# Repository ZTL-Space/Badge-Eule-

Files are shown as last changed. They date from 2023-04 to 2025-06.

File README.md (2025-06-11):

# Entnervte Eule - Lötanleitung

## Einleitung
Die Entnervte Eule ist ein einfacher Bausatz zum selber Zusammenlöten, der im ZTL, dem Zentrum für Technikkultur in Landau, designed wurde.

Die Eule gibt es in 12 verschiedenen Varianten zur Wahl.
Die Platine ist entweder Weiß/Silbern oder Schwarz/Gold.
Die LEDs, welche die Augen darstellen, gibt es in Rot, Gelb, Grün, Blau, langsamer Farbwechsel und schneller Farbwechsel.

## Auspacken

Die Bauteile kommen in einem wiederverschließbaren Beutel, den ihr am Ende mit nach Hause nehmen oder uns zurück geben könnt. Dann wird er wiederverwendet.

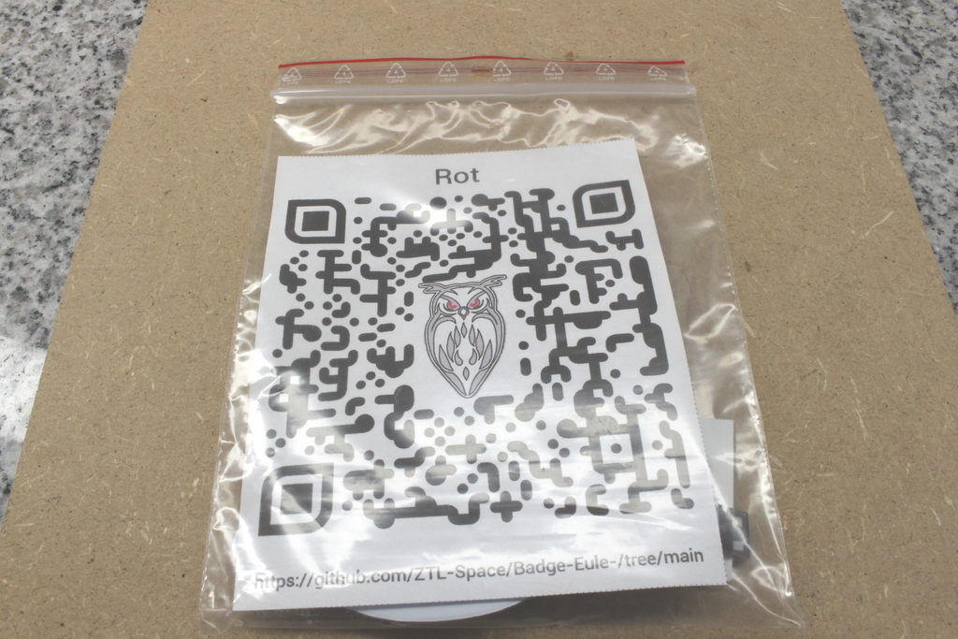
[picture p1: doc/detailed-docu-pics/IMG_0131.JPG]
Wiederverschließbarer Beutel


## Die Bauteile

Folgende Bauteile sollten in der Tüte sein:

- Platine
- Papiergurt mit 2 Widerständen
- Plastikgurt mit 2 LEDs
- Schiebeschalter
- Knopfzellenhalter
- Knopfzelle

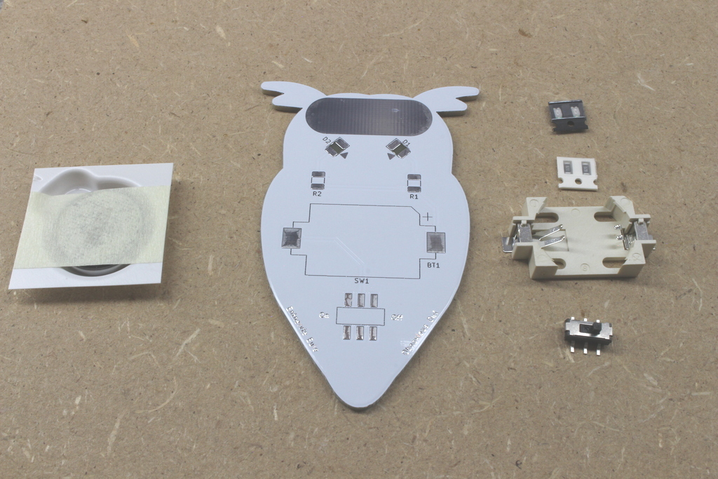
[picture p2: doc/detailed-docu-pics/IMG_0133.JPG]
Bauteile


## Widerstände - R1 und R2

### Auspacken

Zuerst musst du die beiden Widerstände aus dem Papiergurt befreien, indem du mit der Pinzette den Plastikfilm abziehst. Mach das am besten über dem Holzbrett, sodass die Widerstände nicht verloren gehen, sollten sie herunterfallen.

<p float="left">
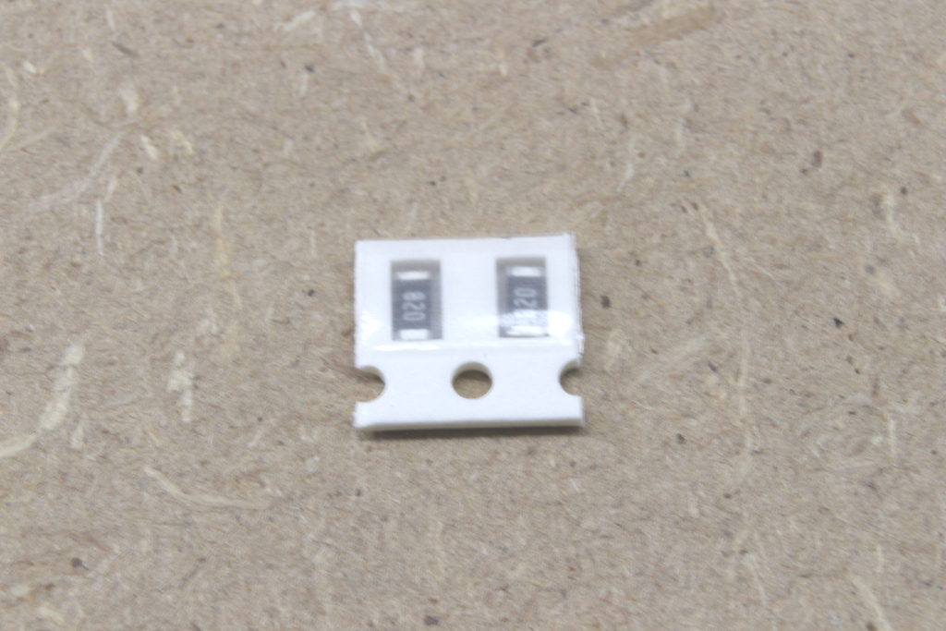
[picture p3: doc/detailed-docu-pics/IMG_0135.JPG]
  
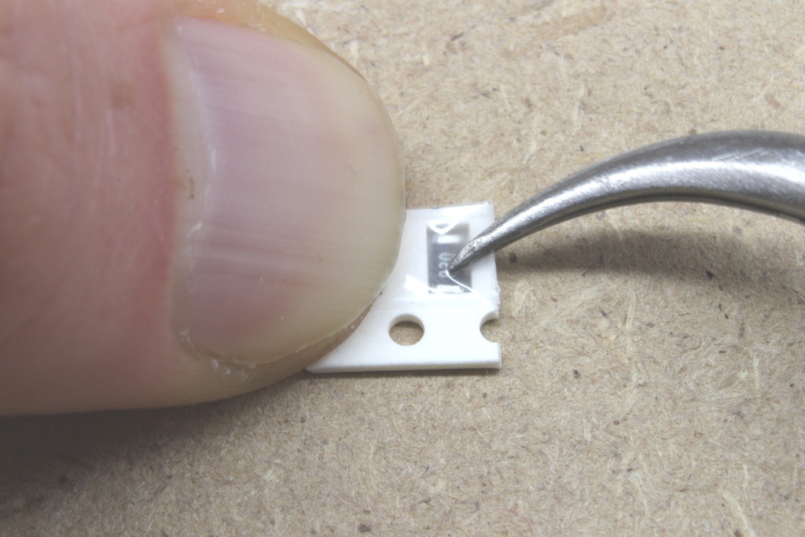
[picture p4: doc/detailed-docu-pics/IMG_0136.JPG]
  
</p>

<p float="left">
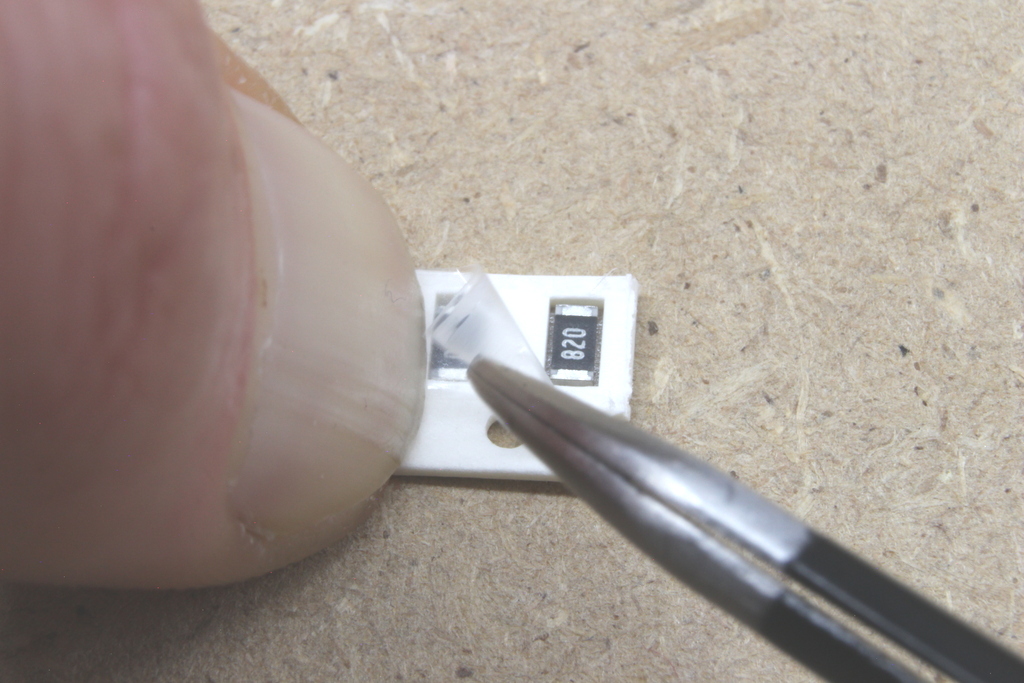
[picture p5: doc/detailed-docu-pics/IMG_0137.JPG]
  
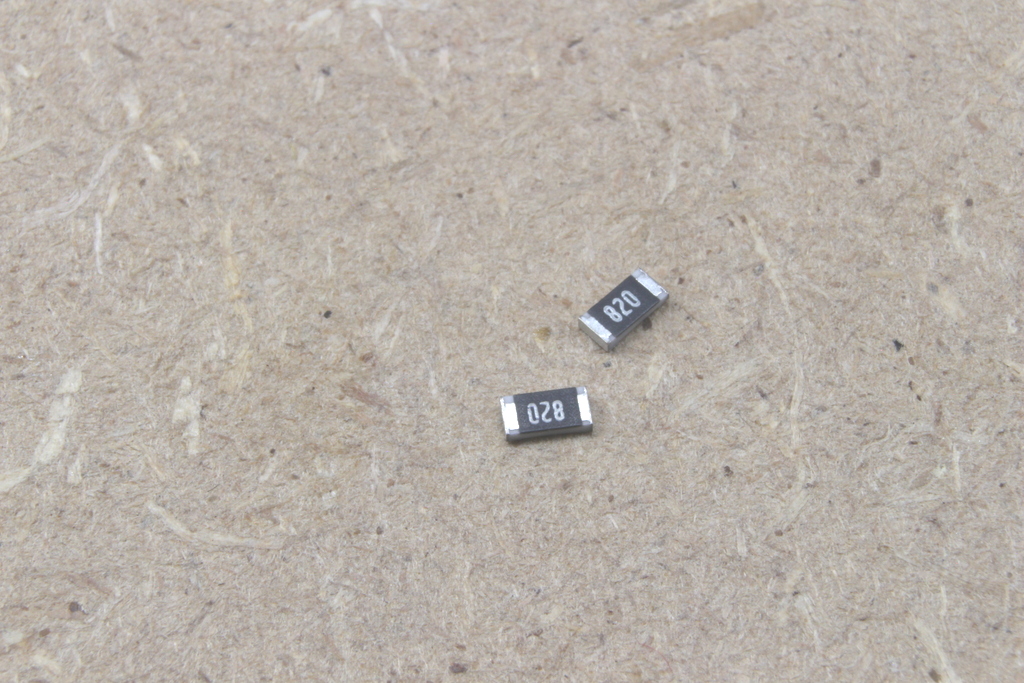
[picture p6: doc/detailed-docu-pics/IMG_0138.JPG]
  
</p>

### Vorverzinnen

Nun musst du eins der beiden Pads von R1 vorverzinnen. Dazu setzt du die Spitze des Lötkolbens auf das Pad und fügst Lötzinn hinzu bis es schmilzt und sich ein kleiner Hügel auf dem Pad bildet. 

Bitte lass das zweite Pad noch frei.

<p float="left">
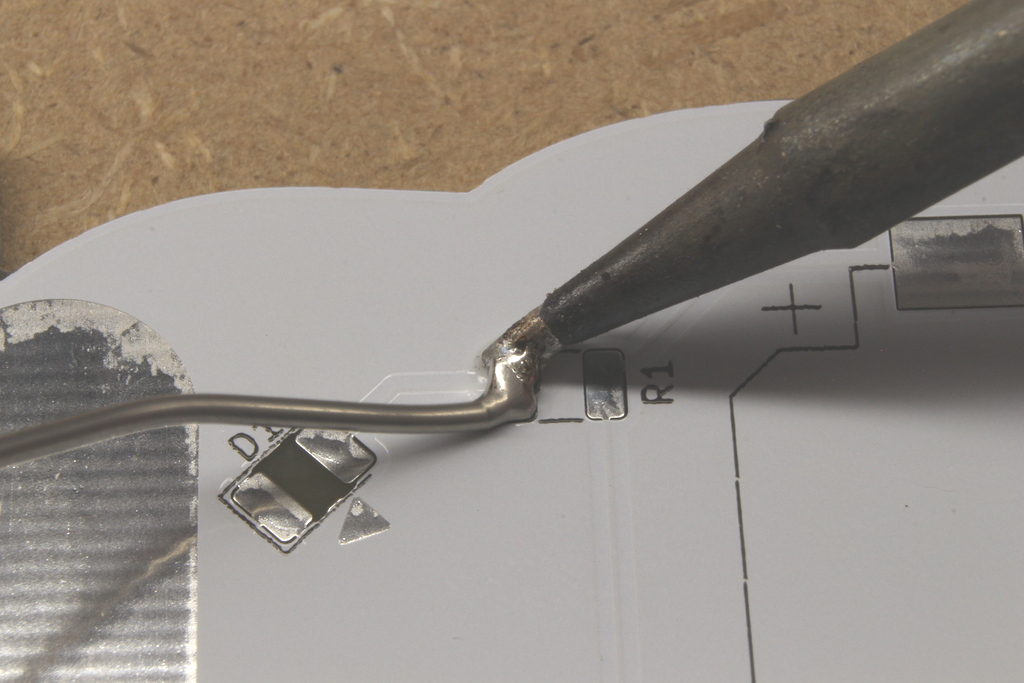
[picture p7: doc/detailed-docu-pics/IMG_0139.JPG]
  
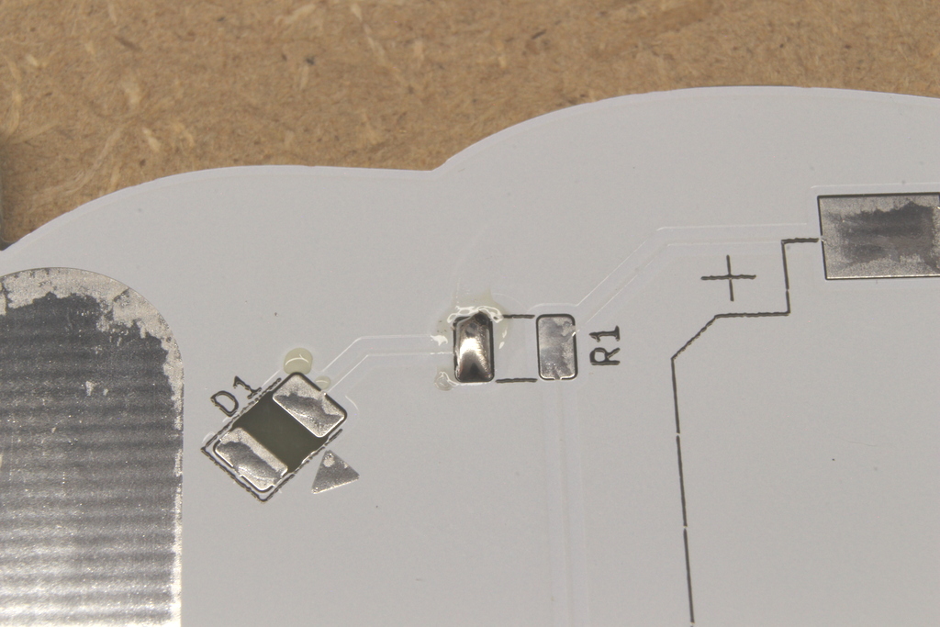
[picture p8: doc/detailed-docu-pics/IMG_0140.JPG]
  
</p>

Das Gleiche machst du bei R2.

<p float="left">
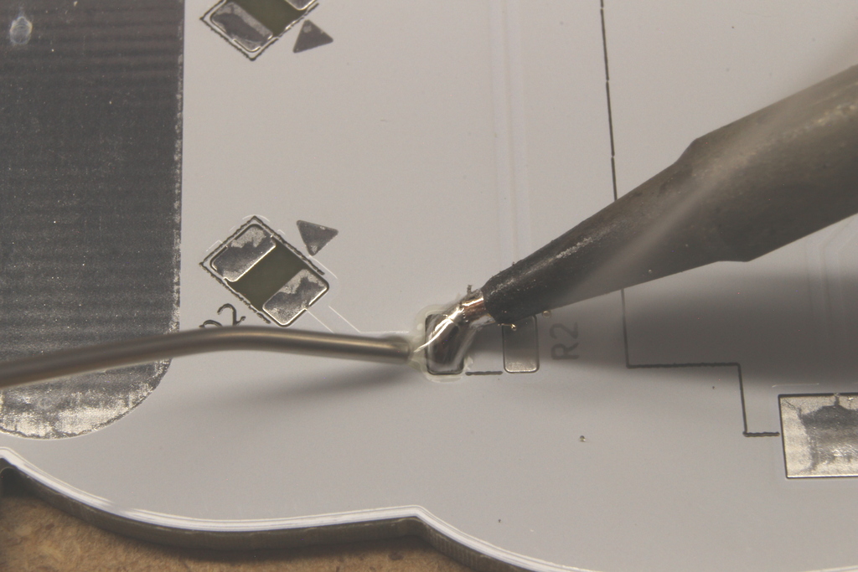
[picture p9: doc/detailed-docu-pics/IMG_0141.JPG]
  
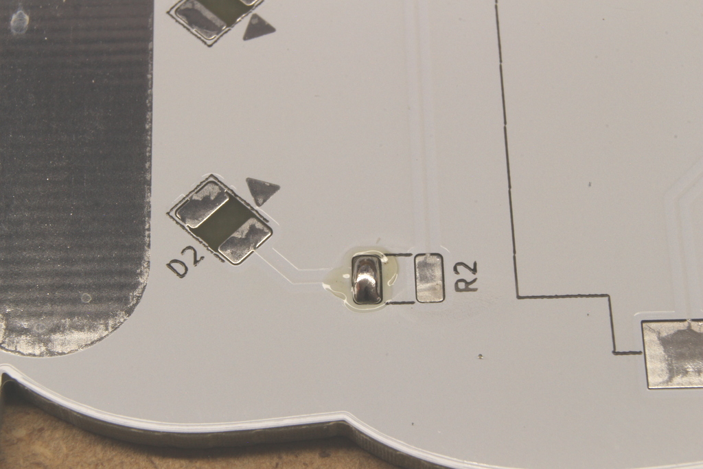
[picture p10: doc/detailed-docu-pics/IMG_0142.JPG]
  
</p>

### Bauteile platzieren

Nimm die Pinzette in deine schwache Hand und den Lötkolben in die starke. Du musst das Lötzinn vom Vorverzinnen auf einem der Pads erneut aufschmelzen und einen Widerstand mit der Pinzette von der Seite hineinschieben. Ist der Widerstand korrekt platziert, nimmst du den Lötkolben weg und wartest ein paar Sekunden, bis das Lötzinn wieder fest ist. Dann kannst du das Bauteil mit der Pinzette loslassen.

<p float="left">
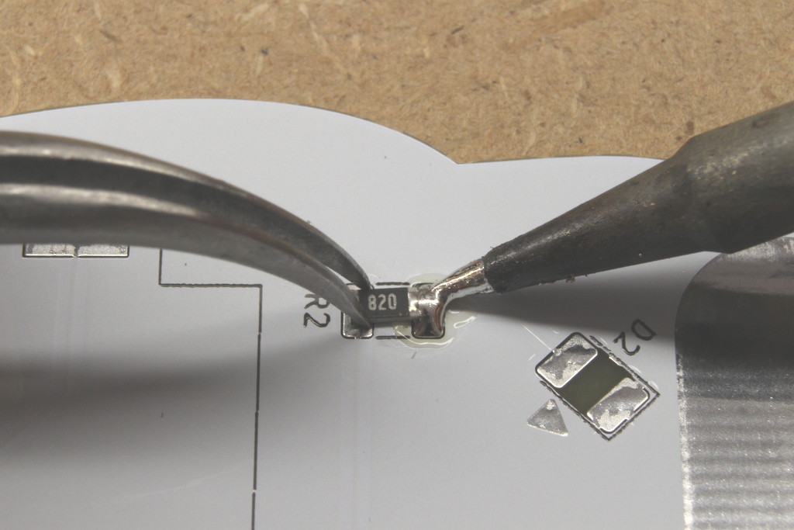
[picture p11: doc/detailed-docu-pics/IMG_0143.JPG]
  
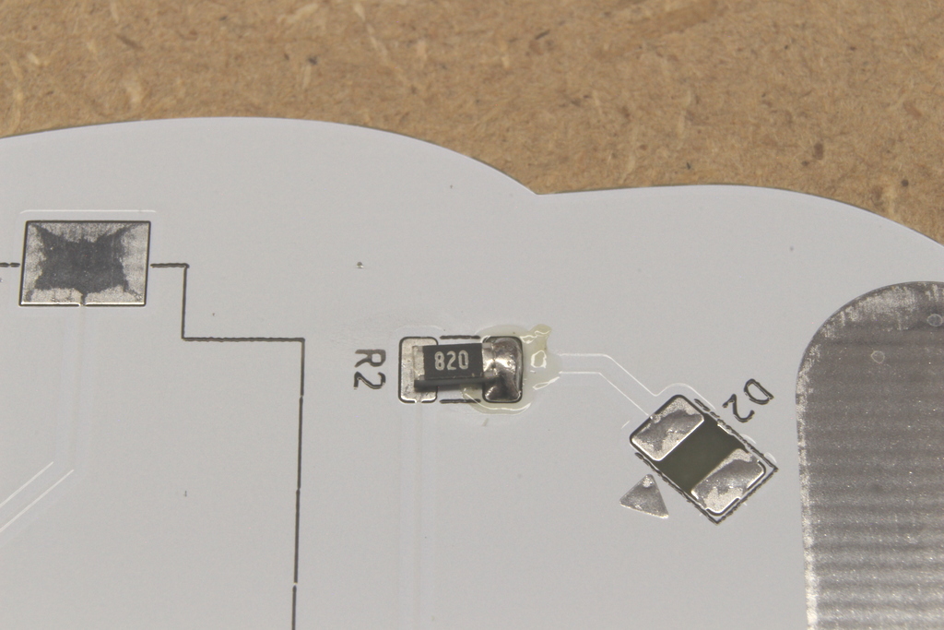
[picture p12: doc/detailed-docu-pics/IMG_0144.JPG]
  
</p>

Das Gleiche wiederholst du für den zweiten Widerstand.

<p float="left">
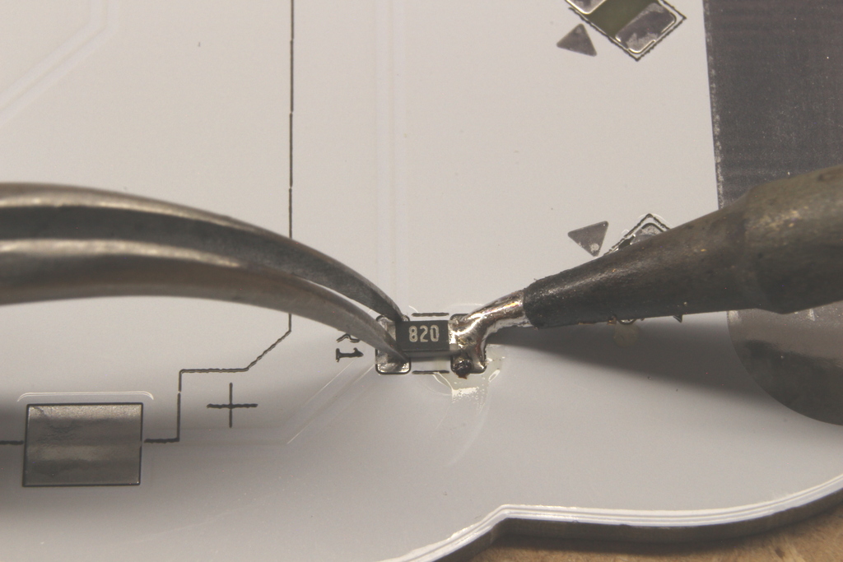
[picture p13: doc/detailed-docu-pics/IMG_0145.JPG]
  
</p>

### Bauteile festlöten

Jetzt sind die Widerstände nur auf einer Seite verbunden. Mit dem Lötzinn und dem Lötkolben musst du auch noch die andere Seite verlöten.

<p float="left">
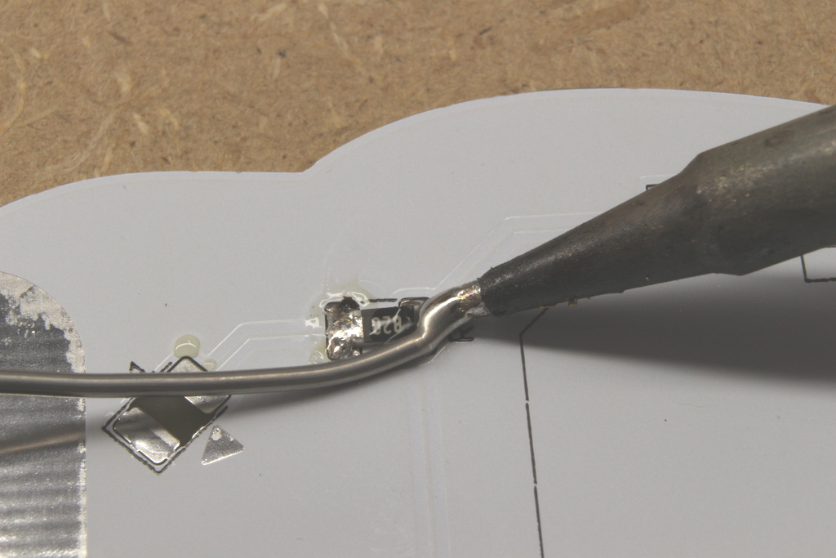
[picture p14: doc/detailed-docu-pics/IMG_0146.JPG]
  
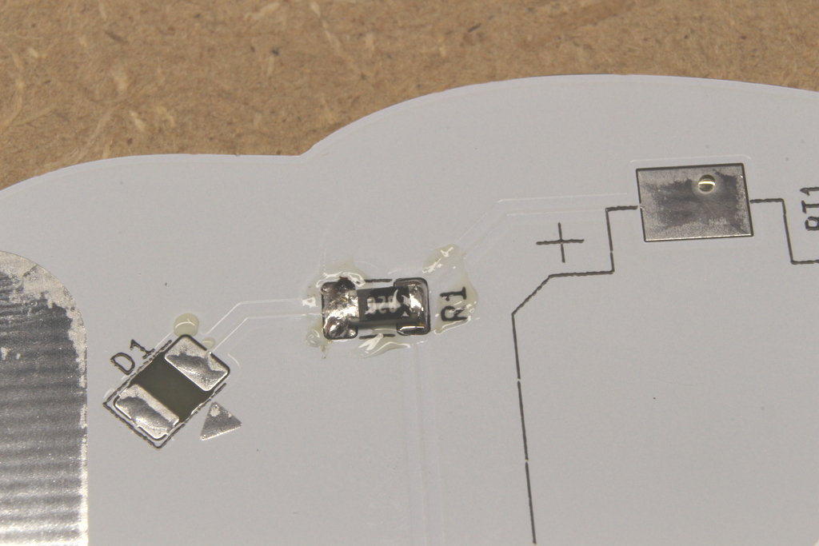
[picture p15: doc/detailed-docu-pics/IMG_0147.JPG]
  
</p>

<p float="left">
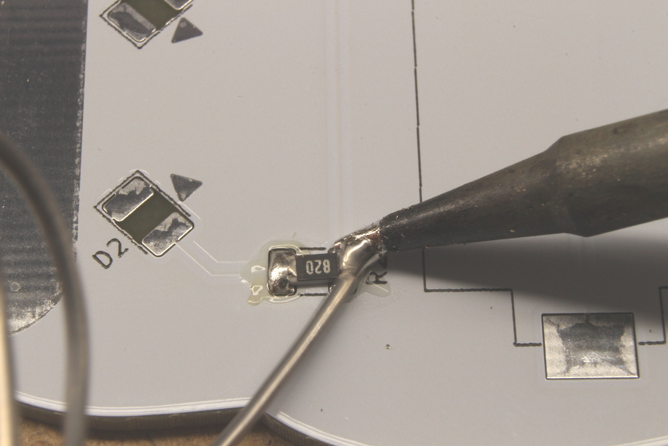
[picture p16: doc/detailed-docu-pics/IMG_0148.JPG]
  
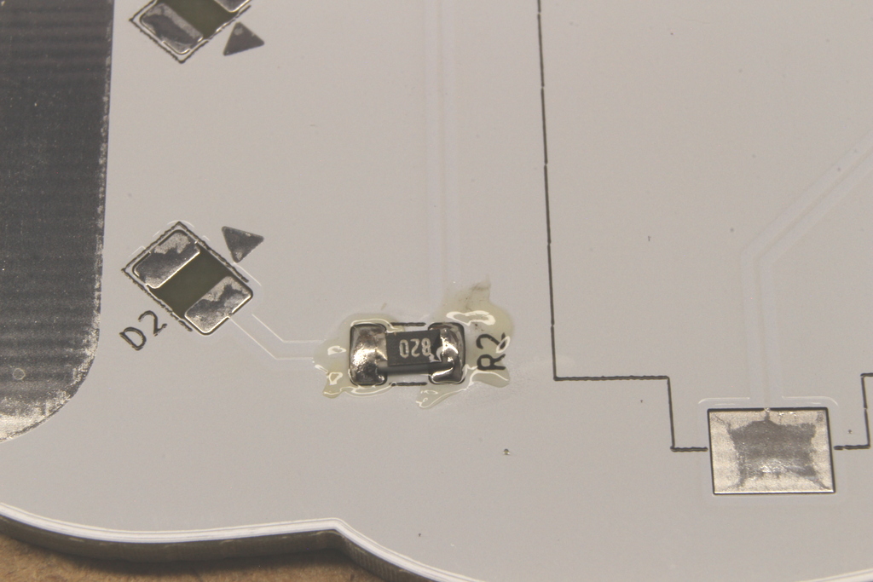
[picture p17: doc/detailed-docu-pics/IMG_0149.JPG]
  
</p>

## LEDs - D1 und D2

### Auspacken

Nun musst du die beiden LEDs aus dem Plastikgurt heraus holen.

<p float="left">
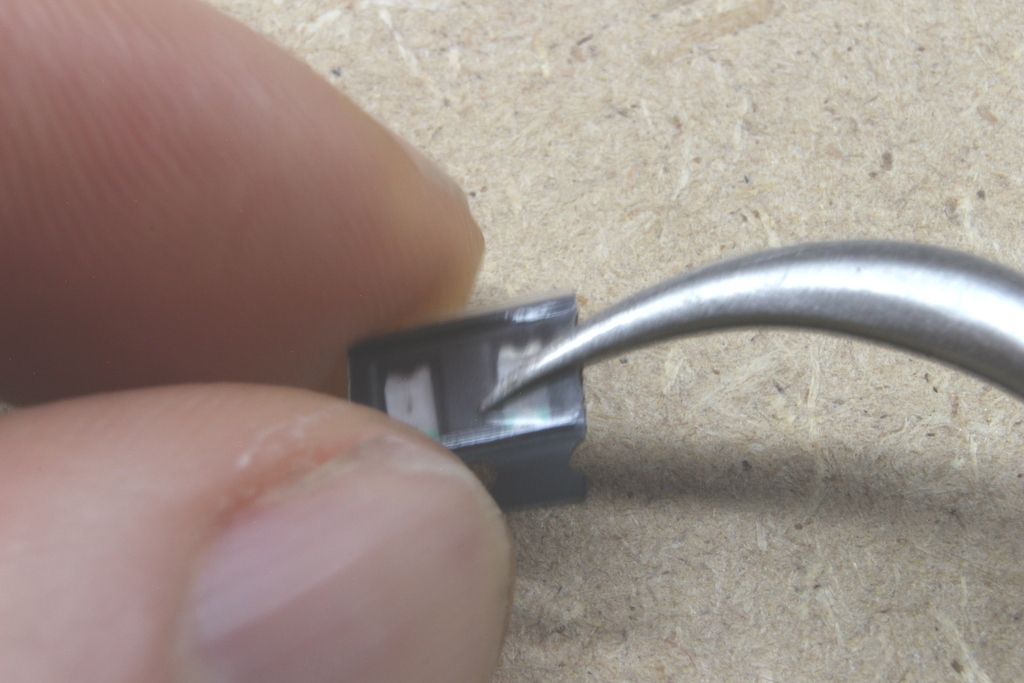
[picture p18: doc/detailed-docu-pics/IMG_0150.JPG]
  
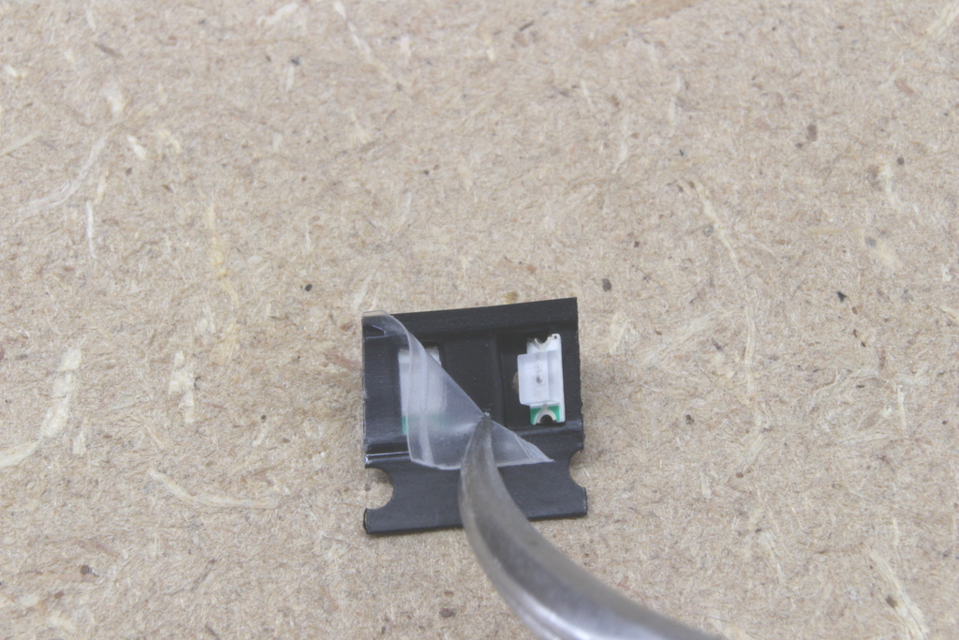
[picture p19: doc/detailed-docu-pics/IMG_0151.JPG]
  
</p>

Die LEDs haben einen Pfeil, der anzeigt in welcher Orientierung sie aufgelötet werden müssen. Je nach Farbe der LED kann der Pfeil unterschiedlich aussehen.

<p float="left">
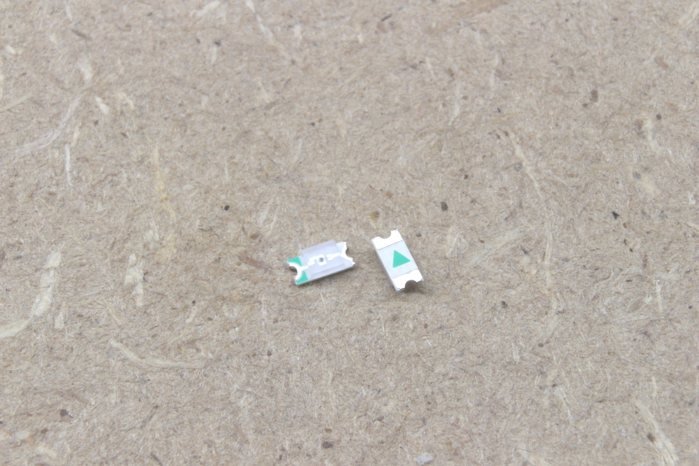
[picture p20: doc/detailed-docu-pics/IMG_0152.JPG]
  
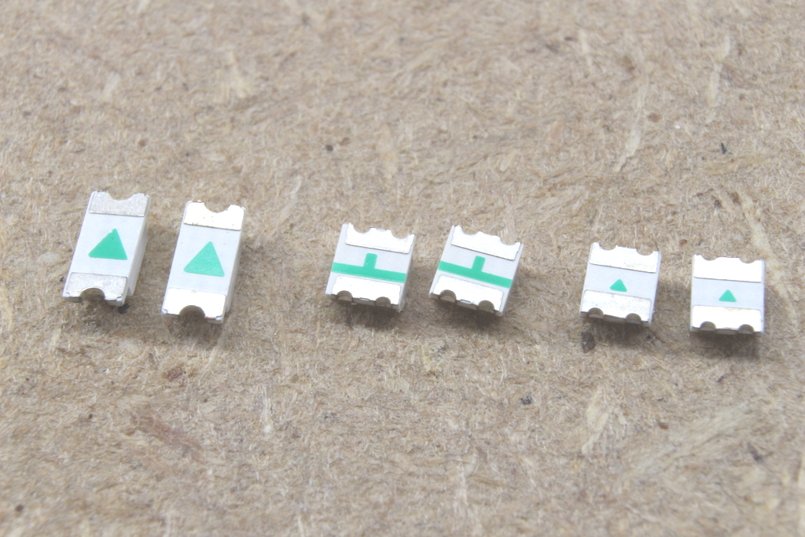
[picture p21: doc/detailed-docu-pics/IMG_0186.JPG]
  
</p>

### Vorverzinnen

Verzinne ein Pad von D1.

<p float="left">
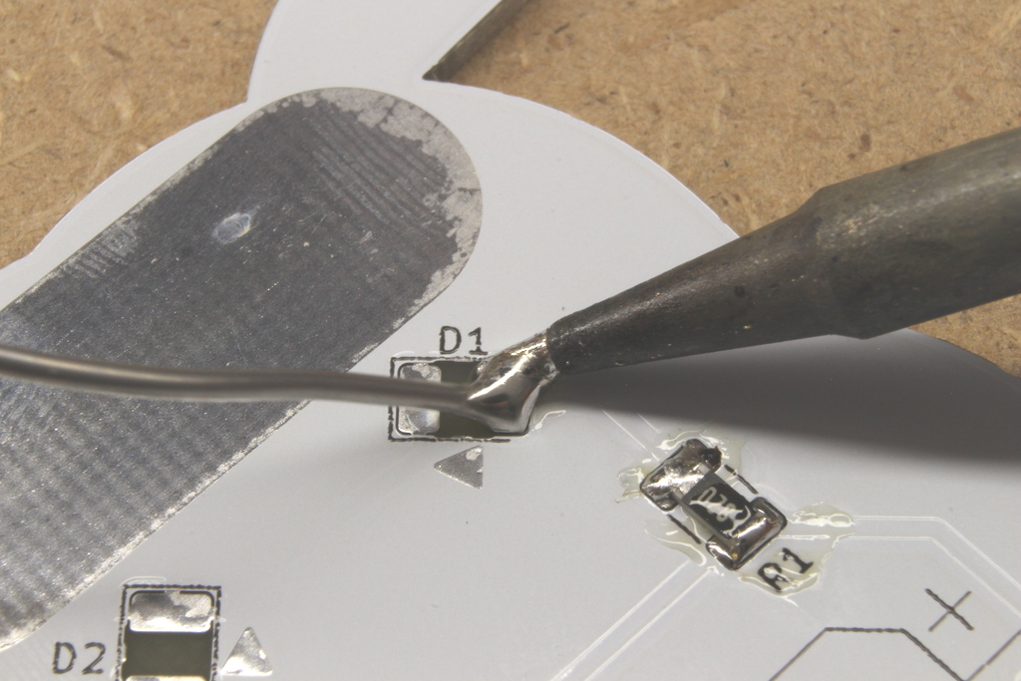
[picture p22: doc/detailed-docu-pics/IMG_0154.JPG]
  
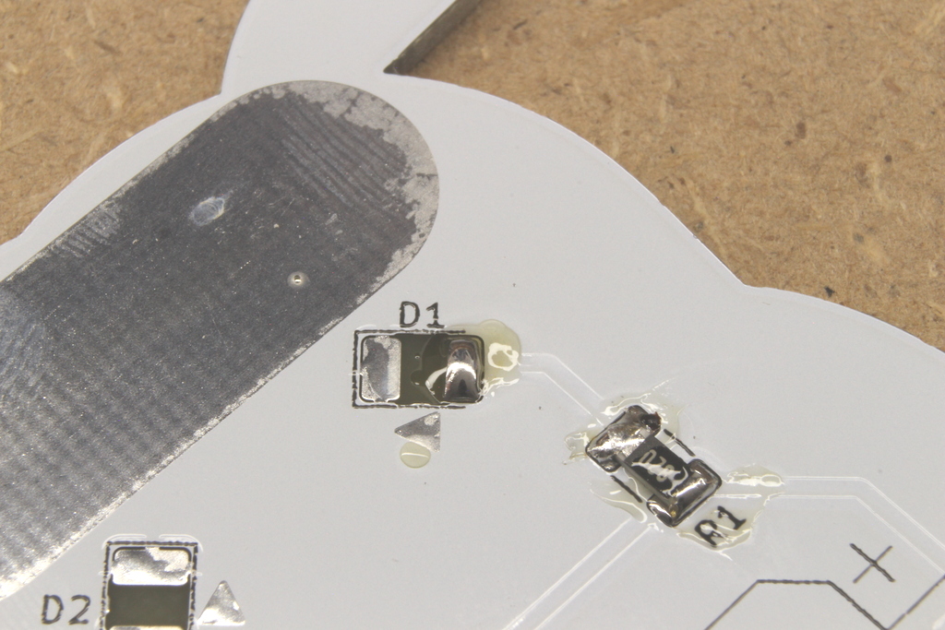
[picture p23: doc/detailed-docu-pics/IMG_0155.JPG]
  
</p>

Das Gleiche machst du bei D2.

<p float="left">
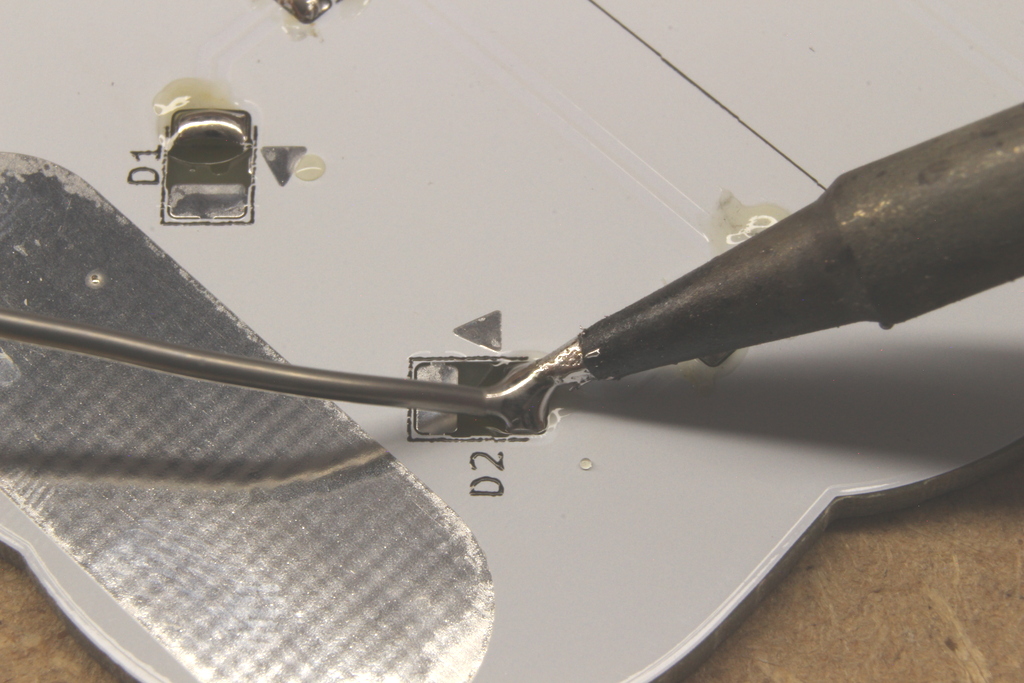
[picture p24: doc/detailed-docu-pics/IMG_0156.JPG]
  
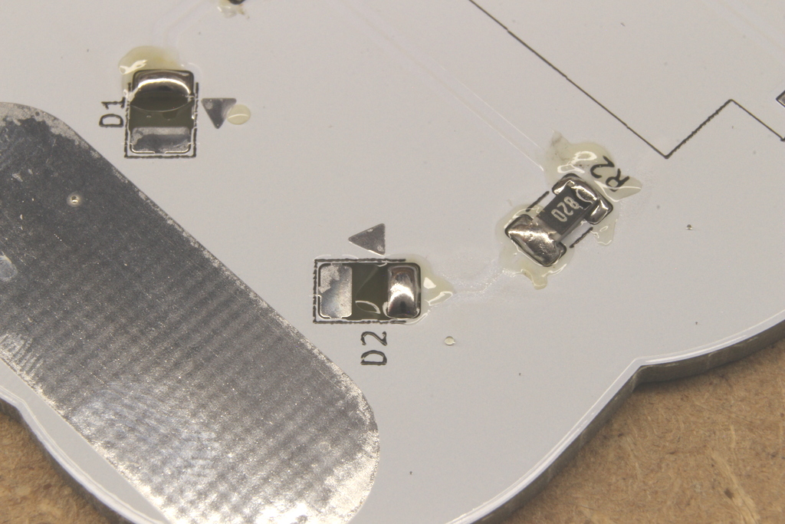
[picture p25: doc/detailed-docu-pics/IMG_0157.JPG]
  
</p>

### Bauteile platzieren

Da wir die LEDs "auf dem Kopf" auflöten, geht das ein bisschen schwieriger als bei den Widerständen, vom Prinzip ist es aber das Gleiche. Befestige zu erst D1. **Achte darauf, dass der Pfeil auf der LED in die gleiche Richtung zeigt wie der Pfeil auf der Platine, in Richtung Kopf der Eule.**

<p float="left">
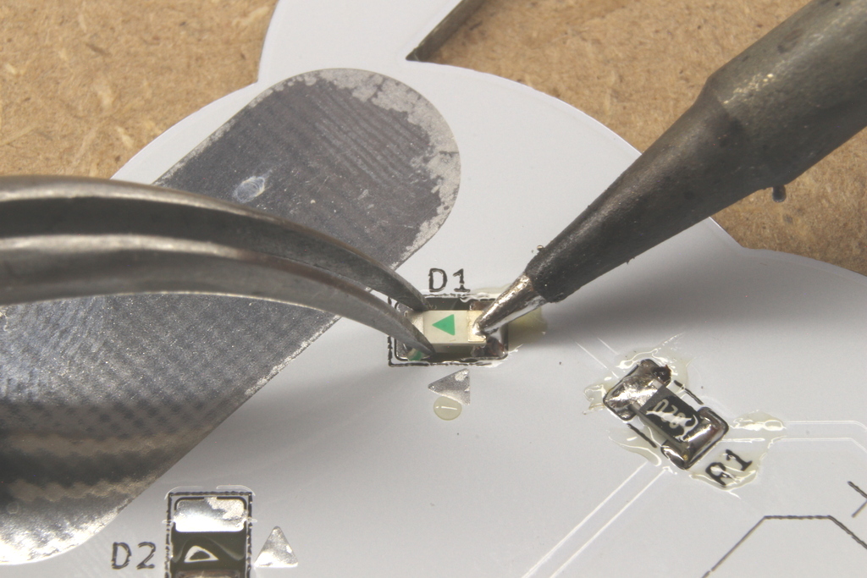
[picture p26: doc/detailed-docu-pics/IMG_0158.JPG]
  
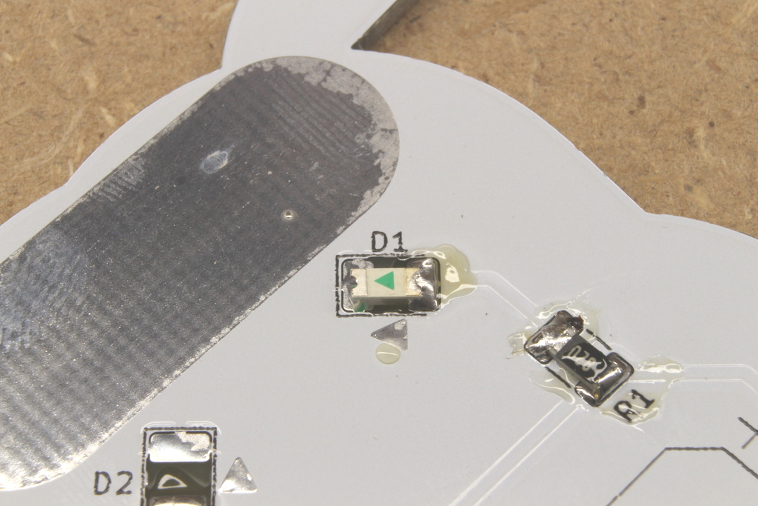
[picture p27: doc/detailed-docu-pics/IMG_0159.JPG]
  
</p>

Das Gleiche wiederholst du für D2.

<p float="left">
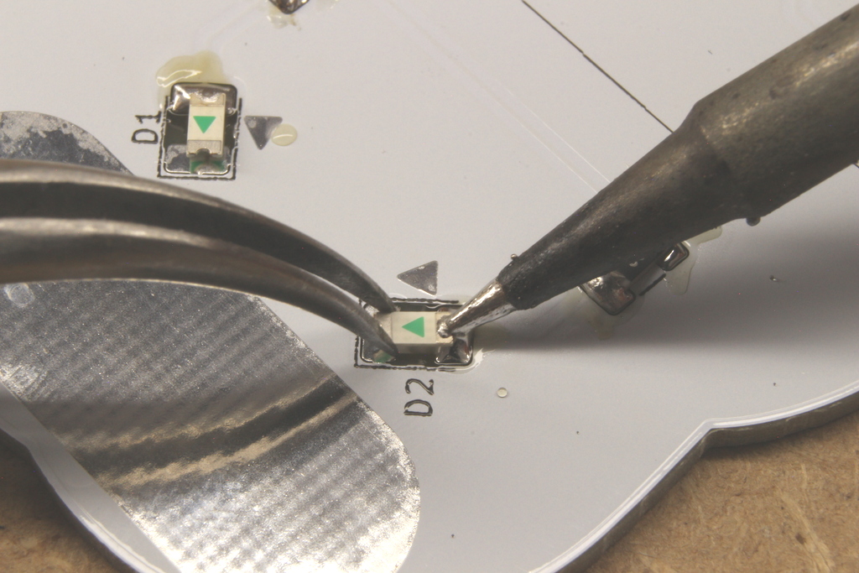
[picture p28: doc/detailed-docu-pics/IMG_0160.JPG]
  
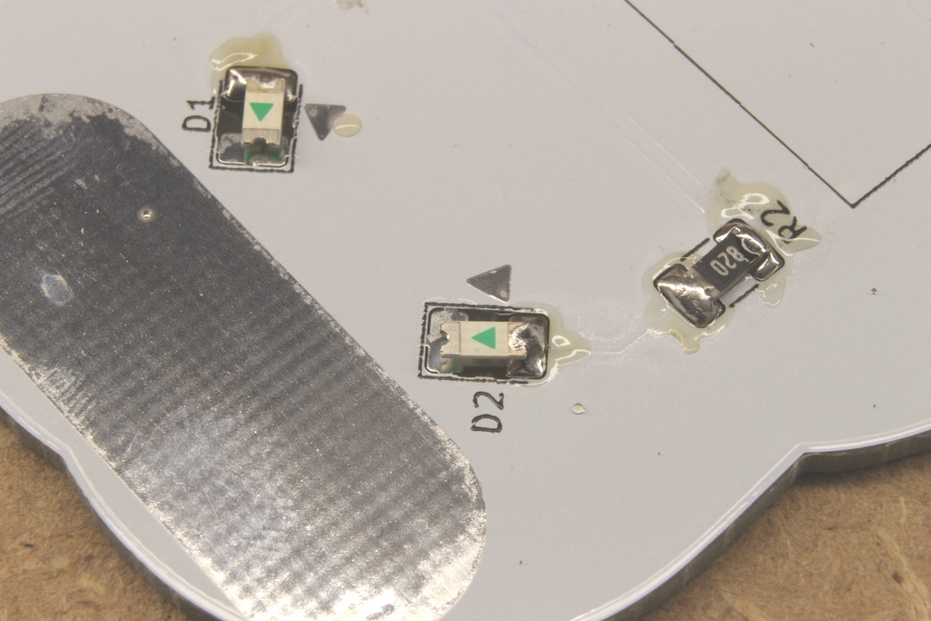
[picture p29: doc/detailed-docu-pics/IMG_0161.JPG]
  
</p>

### Bauteile festlöten

Verlöte jetzt die andere Seite von D1 und D2

<p float="left">
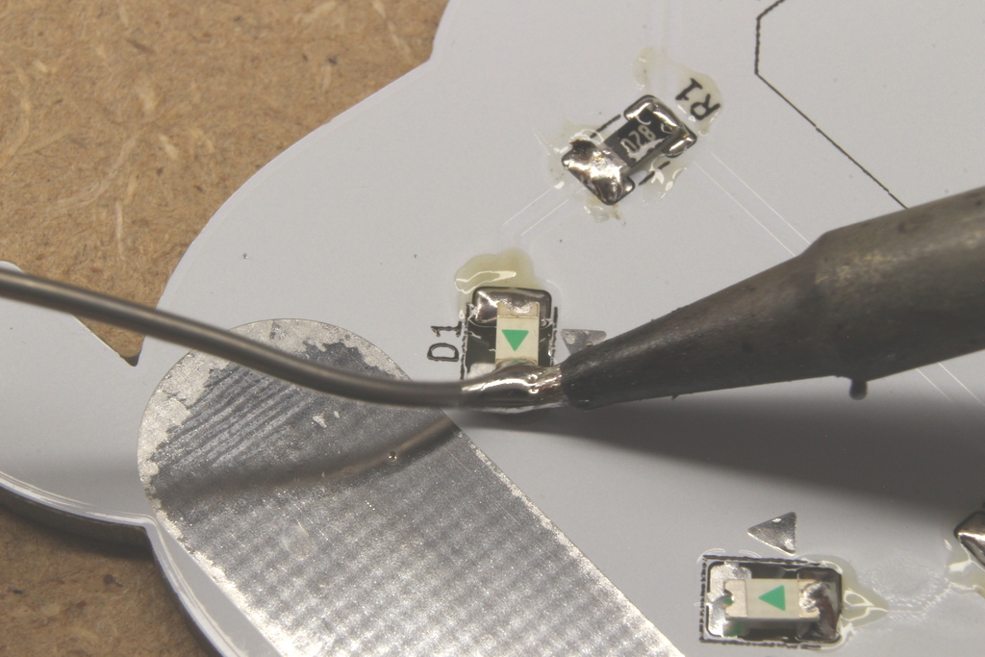
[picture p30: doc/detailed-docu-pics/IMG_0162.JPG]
  
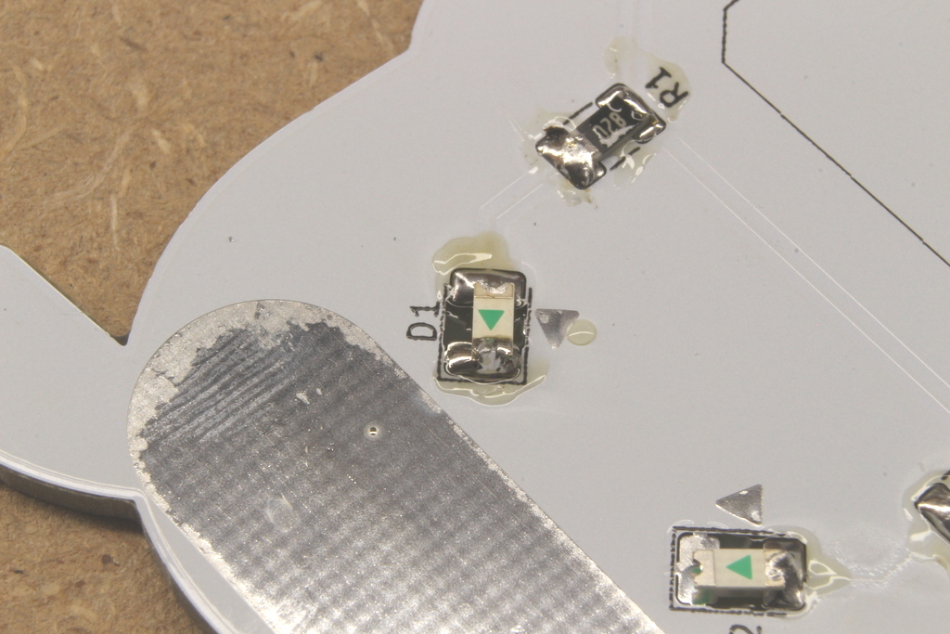
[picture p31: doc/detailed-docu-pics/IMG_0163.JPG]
  
</p>

<p float="left">
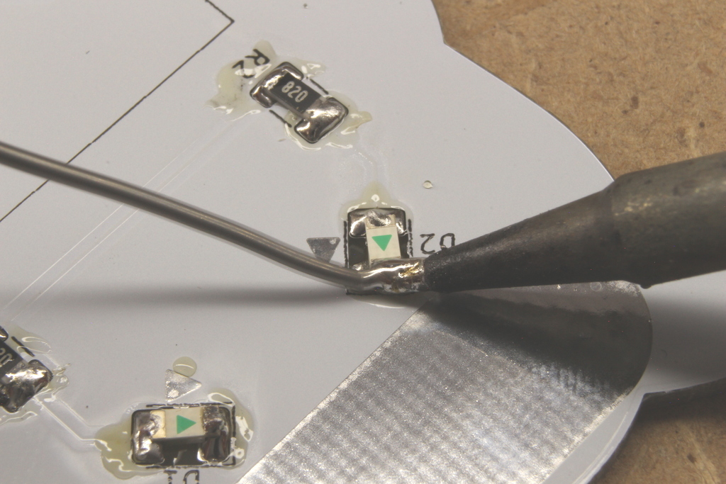
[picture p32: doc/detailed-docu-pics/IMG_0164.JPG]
  
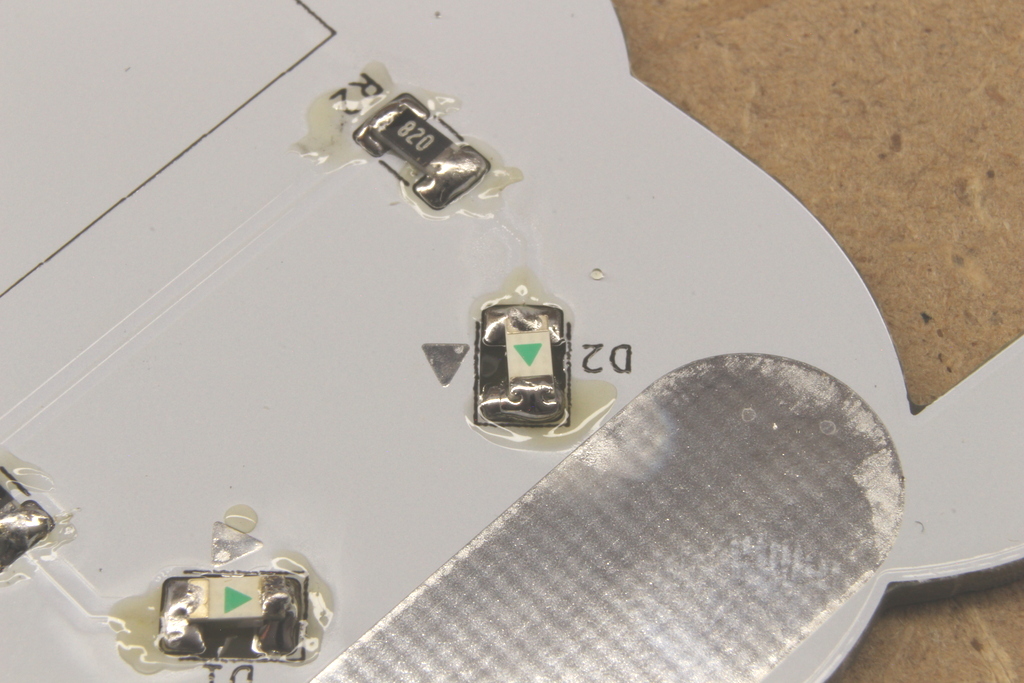
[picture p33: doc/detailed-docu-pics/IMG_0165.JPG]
  
</p>

## Schiebeschalter - SW1

### Vorverzinnen

Verzinne exakt nur ein Pad von SW1. Wirklich. **Nur eins!**

<p float="left">
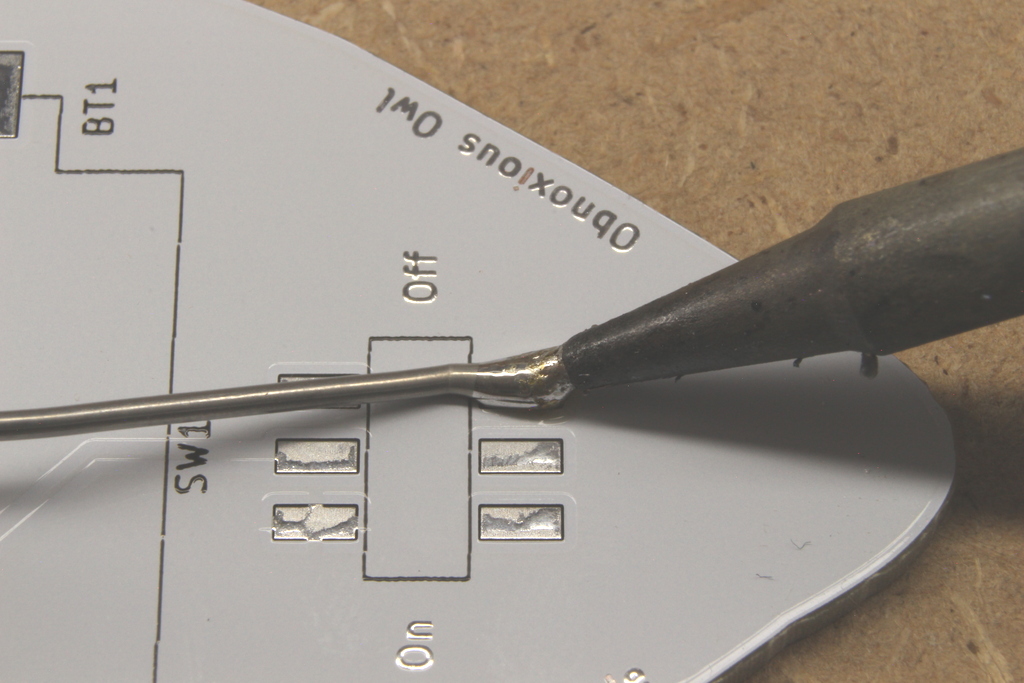
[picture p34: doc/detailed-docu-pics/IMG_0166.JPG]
  
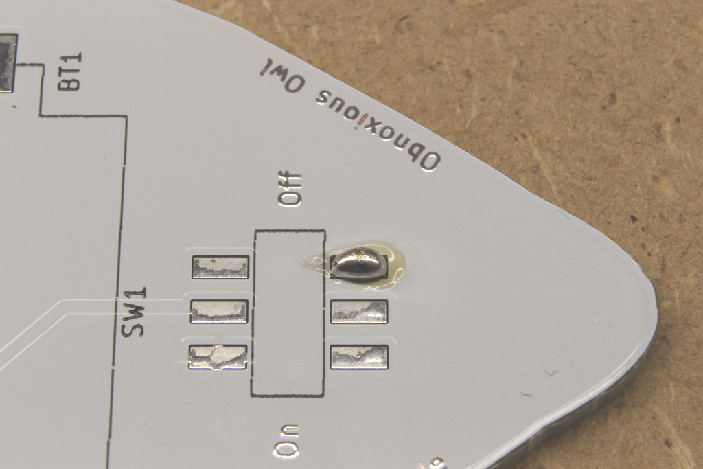
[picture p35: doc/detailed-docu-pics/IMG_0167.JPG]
  
</p>

### Bauteil platzieren

Nimm den Schalter wie gehabt mit der Pinzette. Schmelze das Lötzinn auf und schiebe den Schalter mit einem Beinchen in das flüssige Lötzinn.

<p float="left">
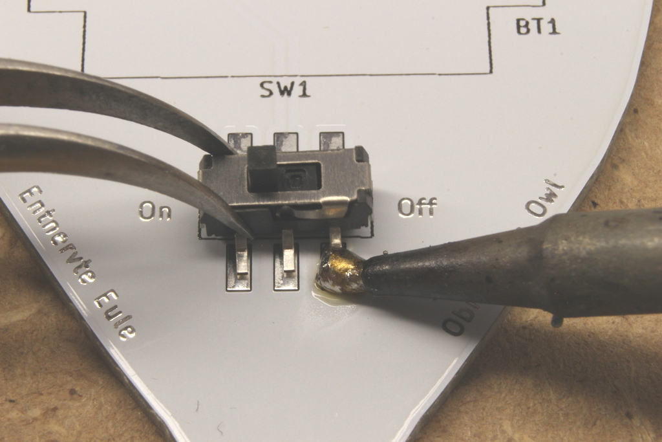
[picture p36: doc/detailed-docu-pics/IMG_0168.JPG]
  
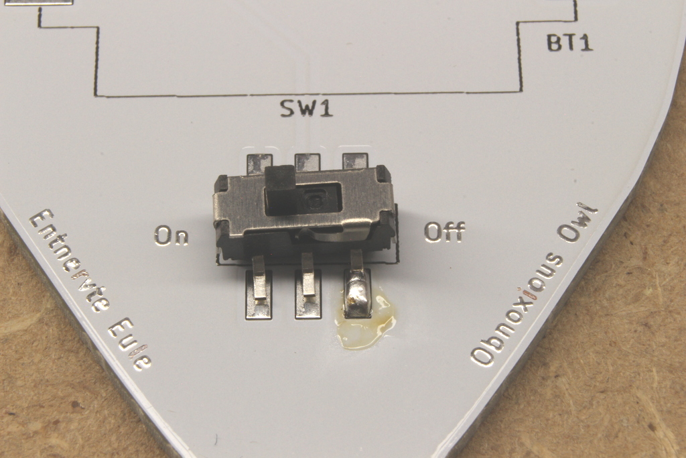
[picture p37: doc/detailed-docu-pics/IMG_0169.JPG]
  
</p>

### Bauteil festlöten

Befestige die restlichen Beinchen

<p float="left">
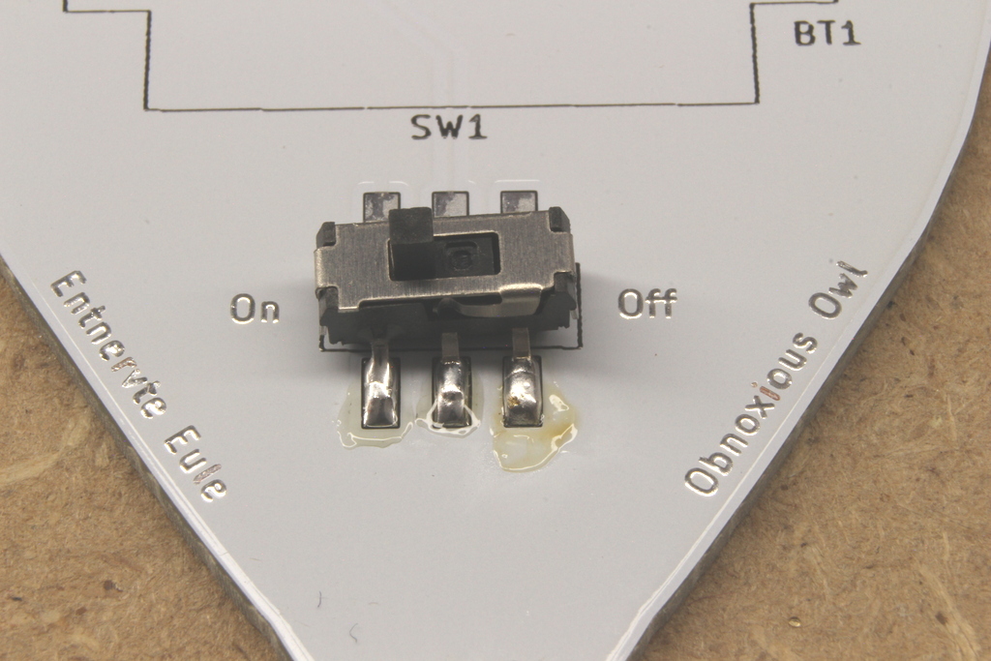
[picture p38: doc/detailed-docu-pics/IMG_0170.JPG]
  
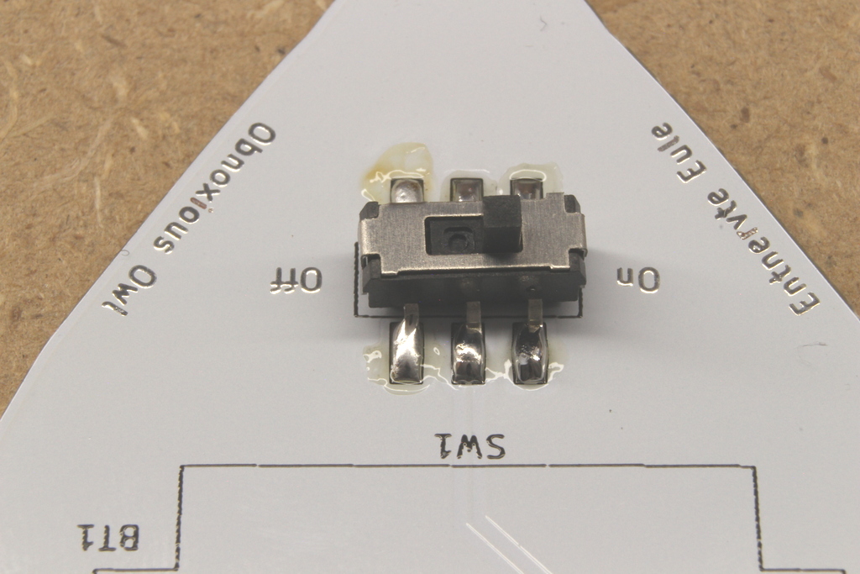
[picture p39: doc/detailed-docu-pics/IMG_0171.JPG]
  
</p>

## Knopfzellenhalter - BT1

### Vorverzinnen

Verzinne ein Pad des Knopfzellenhalters

<p float="left">
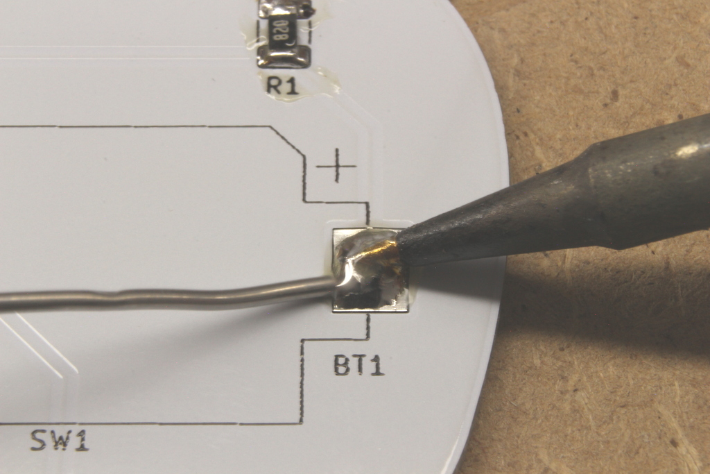
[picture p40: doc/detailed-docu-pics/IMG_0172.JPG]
  
  
</p>

### Bauteil platzieren

Den Knopfzellenhalter kannst du mit der Hand platzieren.
Drücke mit der Lötkolbenspitze auf das Metallfähnchen bis das darunter liegende Lötzinn aufgeschmolzen ist und der Halter einsinkt.
**Achte darauf, den Halter richtig herum anzulöten. Eine Ecke des Halters ist abgeschrägt. Diese Schräge kannst du auch auf dem Bestückungsdruck sehen.**

<p float="left">
  
</p>

### Bauteil festlöten

Verlöte die zweite Lötfahne des Knopfzellenhalters.

<p float="left">
  
</p>

## Knopfzelle

### Auspacken

Entferne das Kreppband von der Knopfzelle.

<p float="left">
  
  
</p>

### Einlegen

Lege die Knopfzelle mit der glatten Seite nach oben in den Knopfzellenhalter ein. Achte darauf, dass die Knopfzelle **unter** den kurzen Metallkontakten ist und drücke sie mit dem Daumen ein, bis sie einrastet.

<p float="left">
  
  
</p>

<p float="left">
  
</p>

### Anschalten und ausprobieren

Wenn du den Schalter auf On stellst, sollten beide LEDs leuchten.

<p float="left">
  
  
</p>

Glückwunsch! Wirf den Müll in die Müllbehälter und lege die Werkzeuge wieder auf das Brett.

Sollte die Eule nicht funktionieren, sag uns bescheid und wir helfen dir den Fehler zu finden.

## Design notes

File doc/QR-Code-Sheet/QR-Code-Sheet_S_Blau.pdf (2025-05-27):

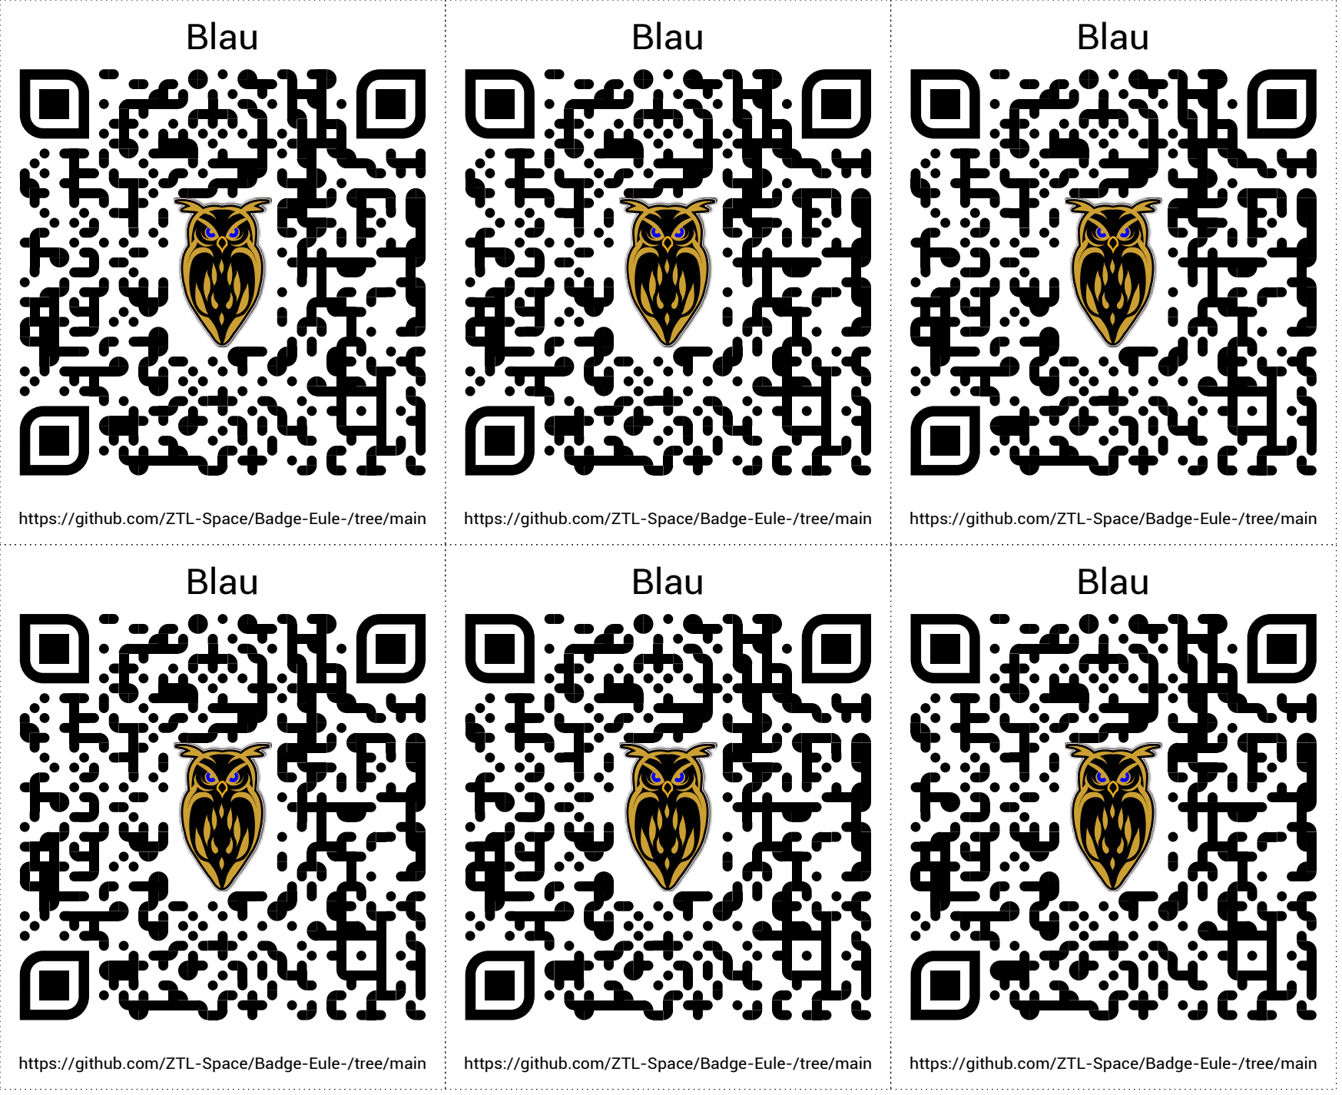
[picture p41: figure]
https://github.com/ZTL-Space/Badge-Eule-/tree/main; Blau

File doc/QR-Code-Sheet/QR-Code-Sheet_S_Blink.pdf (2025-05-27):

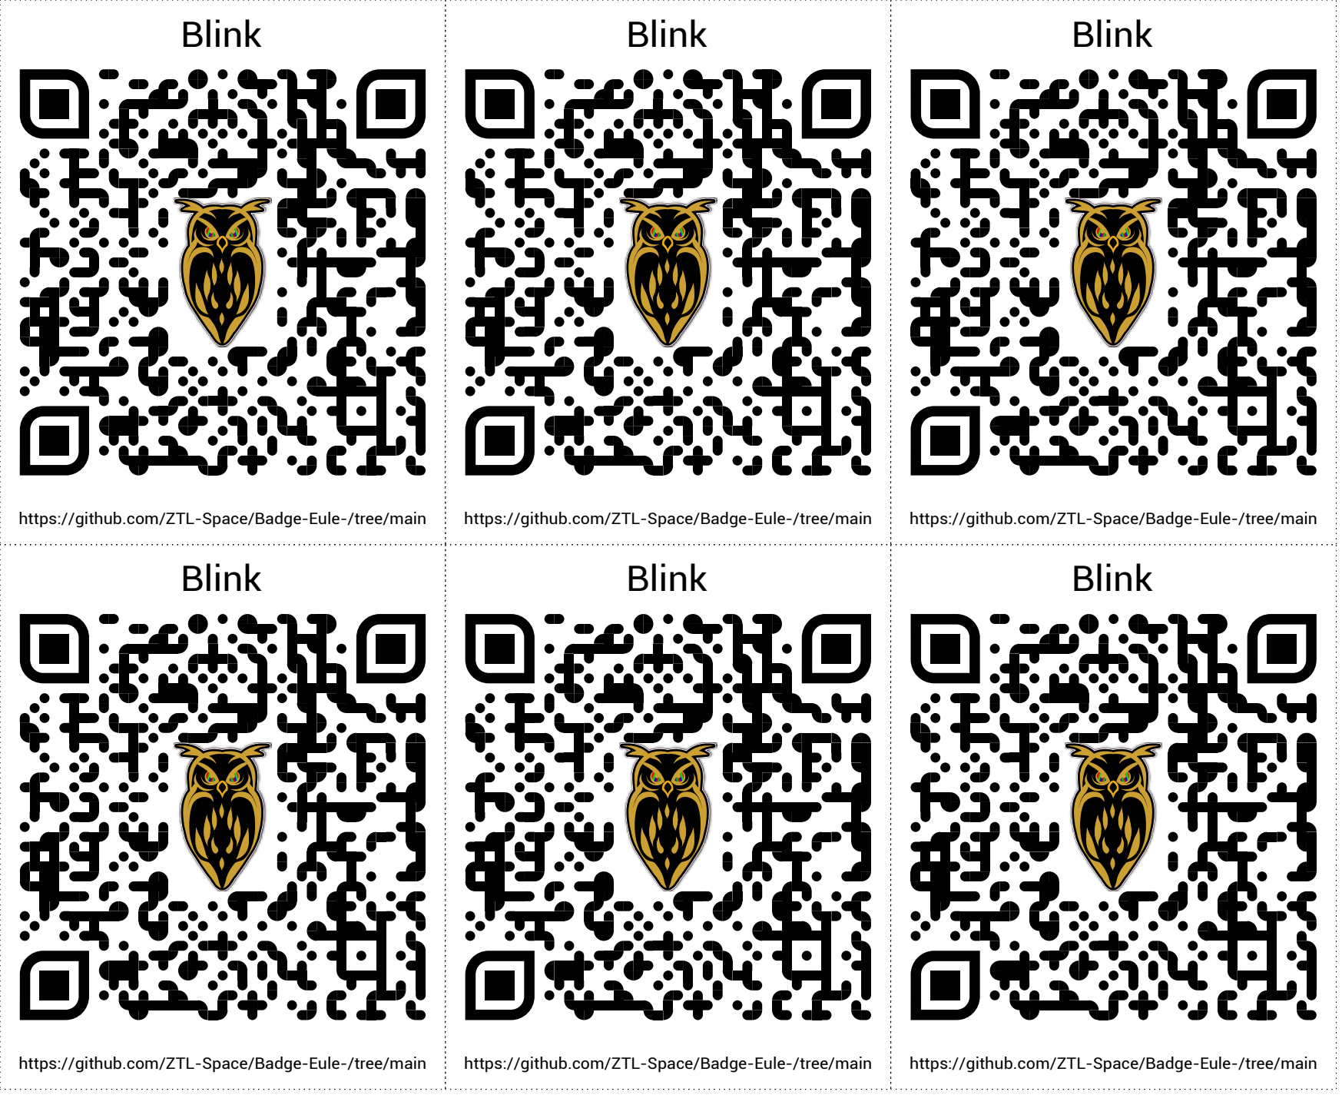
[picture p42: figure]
https://github.com/ZTL-Space/Badge-Eule-/tree/main; Blink

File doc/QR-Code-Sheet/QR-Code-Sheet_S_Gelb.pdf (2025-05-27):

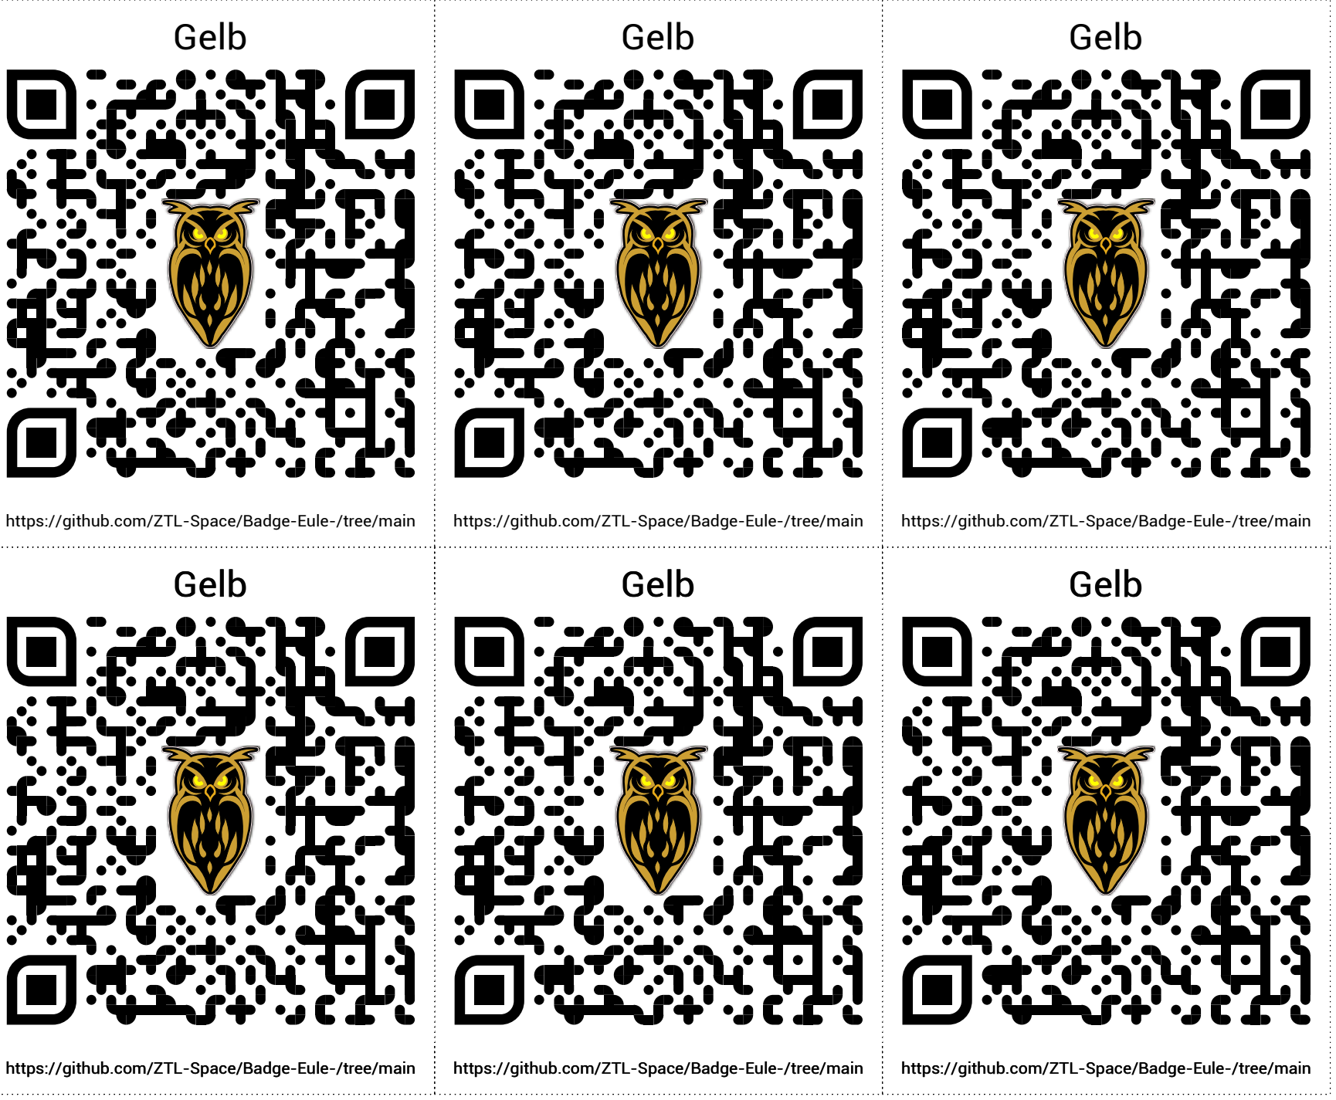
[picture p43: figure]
https://github.com/ZTL-Space/Badge-Eule-/tree/main; Gelb

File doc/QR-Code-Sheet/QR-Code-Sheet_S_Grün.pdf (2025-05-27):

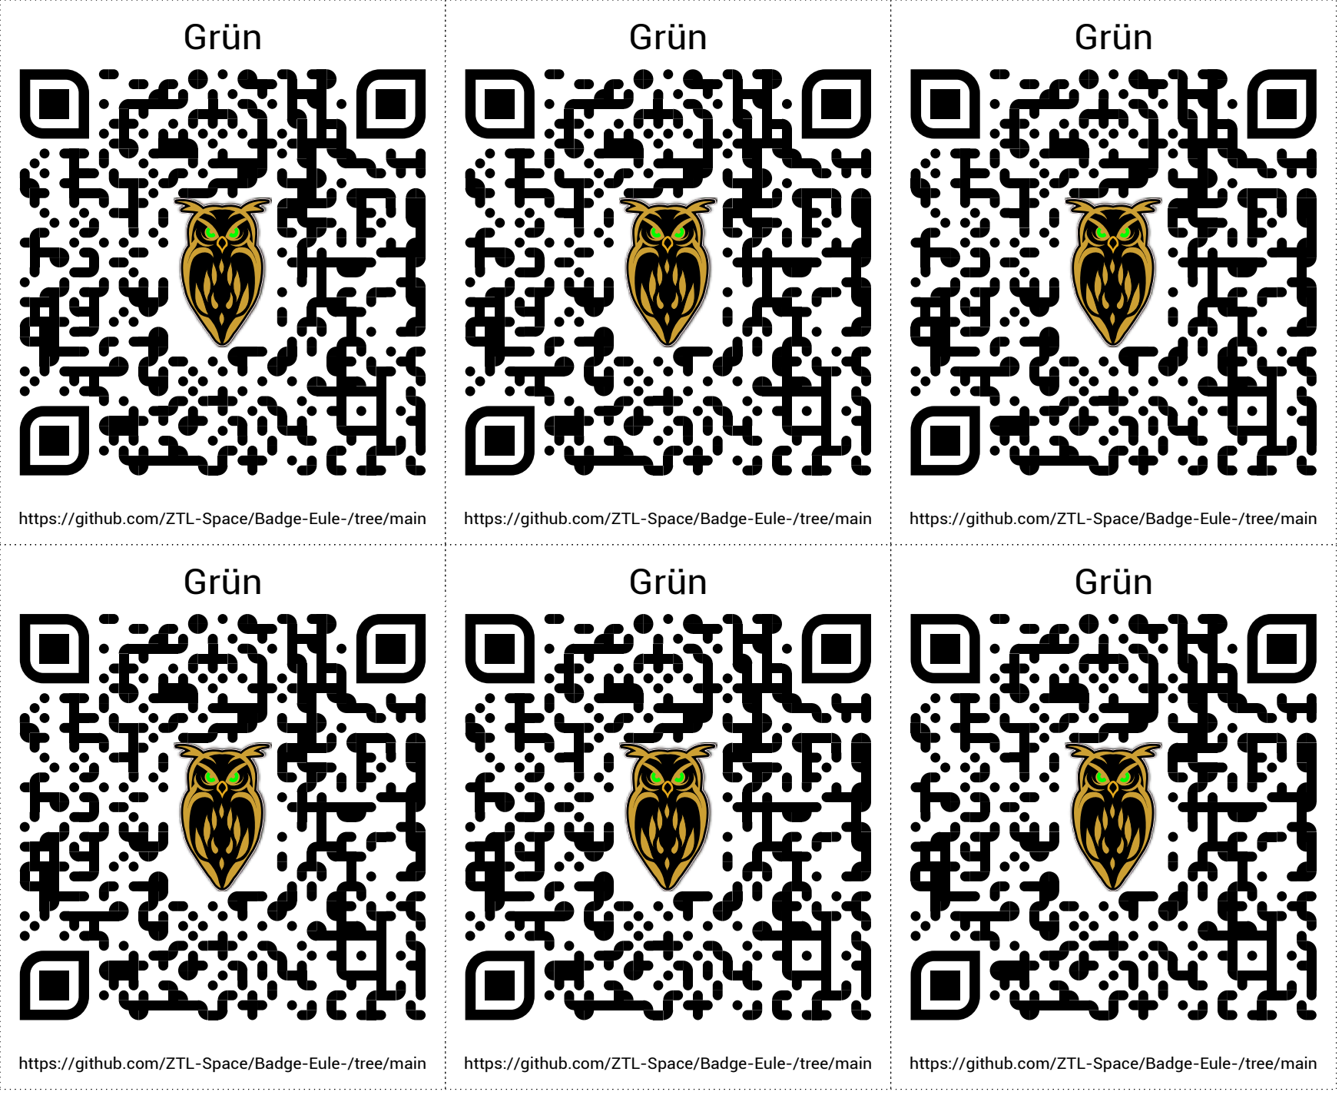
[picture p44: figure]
https://github.com/ZTL-Space/Badge-Eule-/tree/main; Grün

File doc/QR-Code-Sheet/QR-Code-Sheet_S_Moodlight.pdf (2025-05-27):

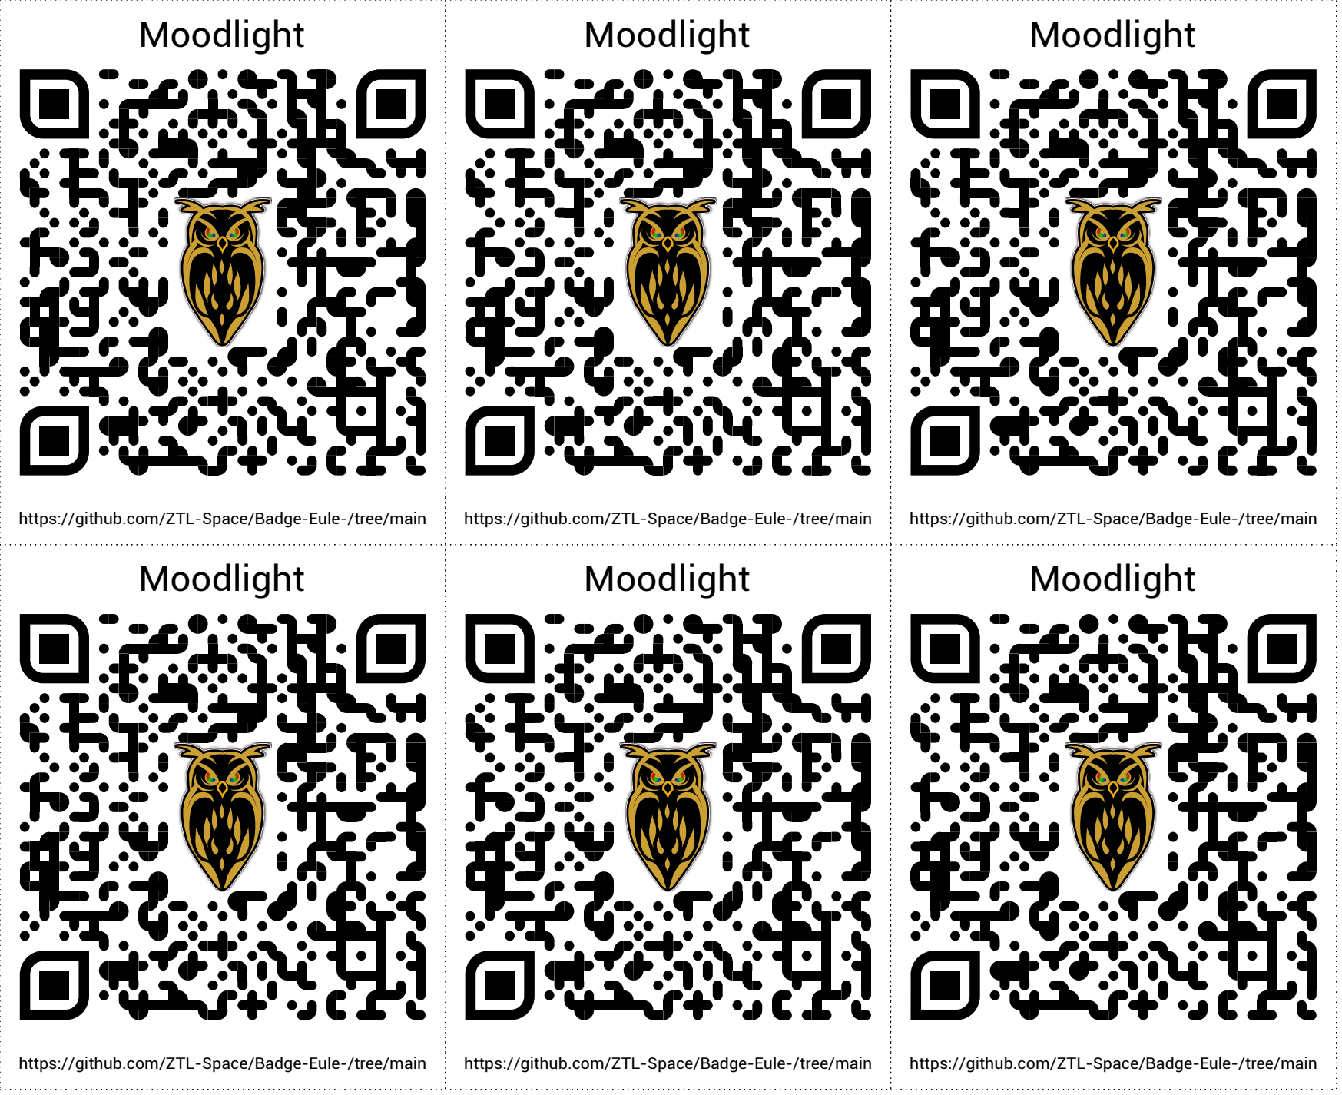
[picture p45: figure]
https://github.com/ZTL-Space/Badge-Eule-/tree/main; Moodlight

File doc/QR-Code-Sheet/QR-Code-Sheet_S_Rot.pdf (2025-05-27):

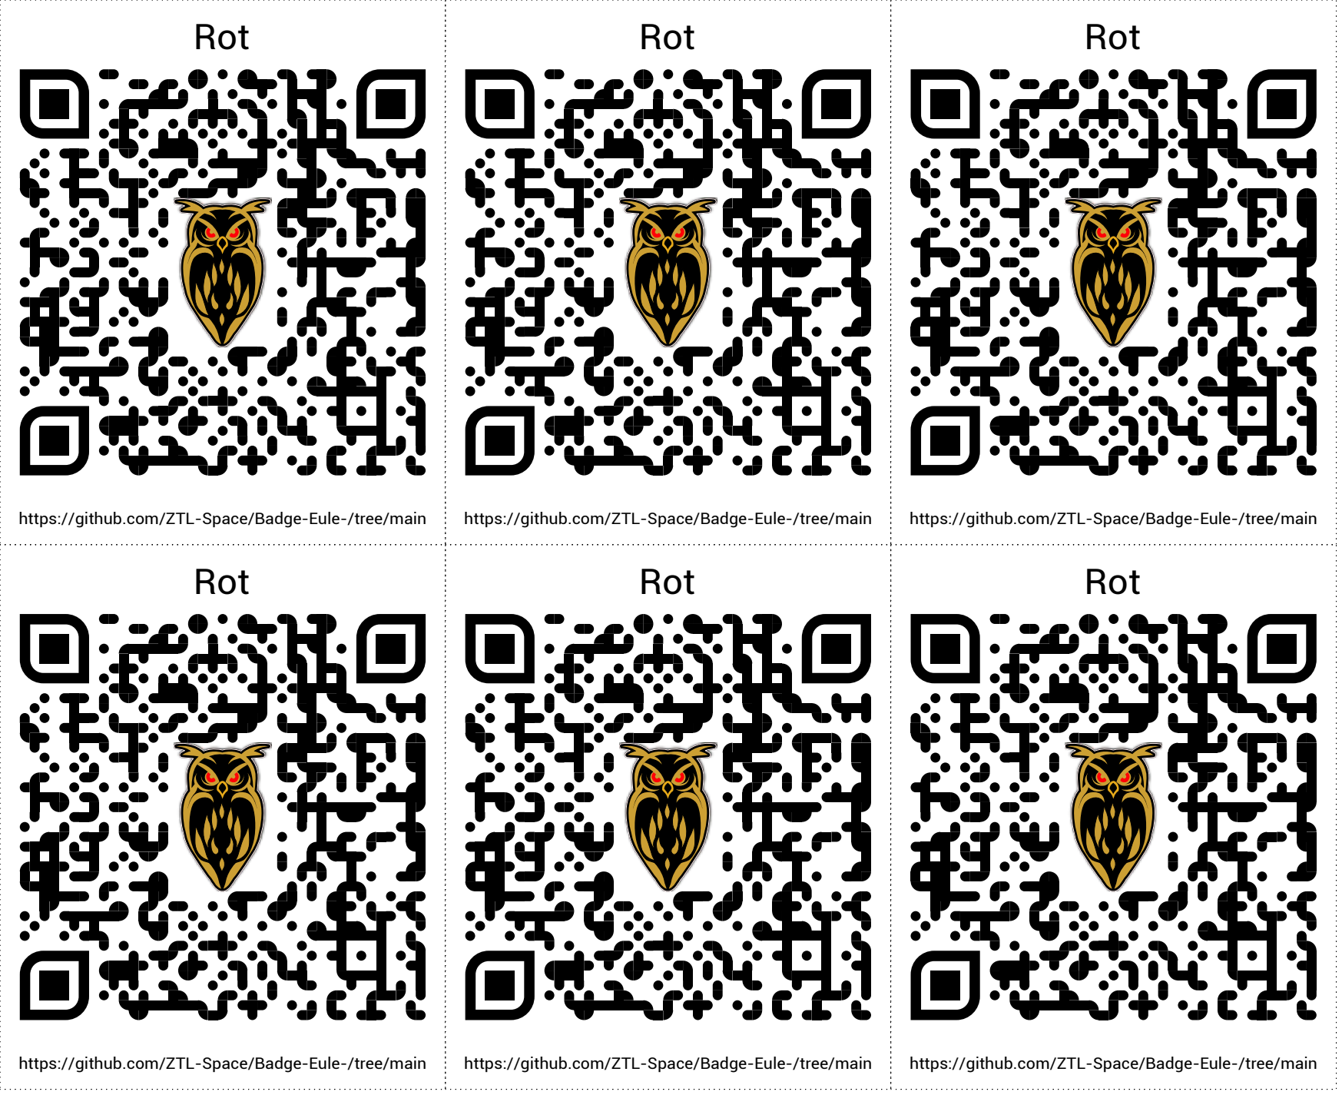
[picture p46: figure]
https://github.com/ZTL-Space/Badge-Eule-/tree/main; Rot

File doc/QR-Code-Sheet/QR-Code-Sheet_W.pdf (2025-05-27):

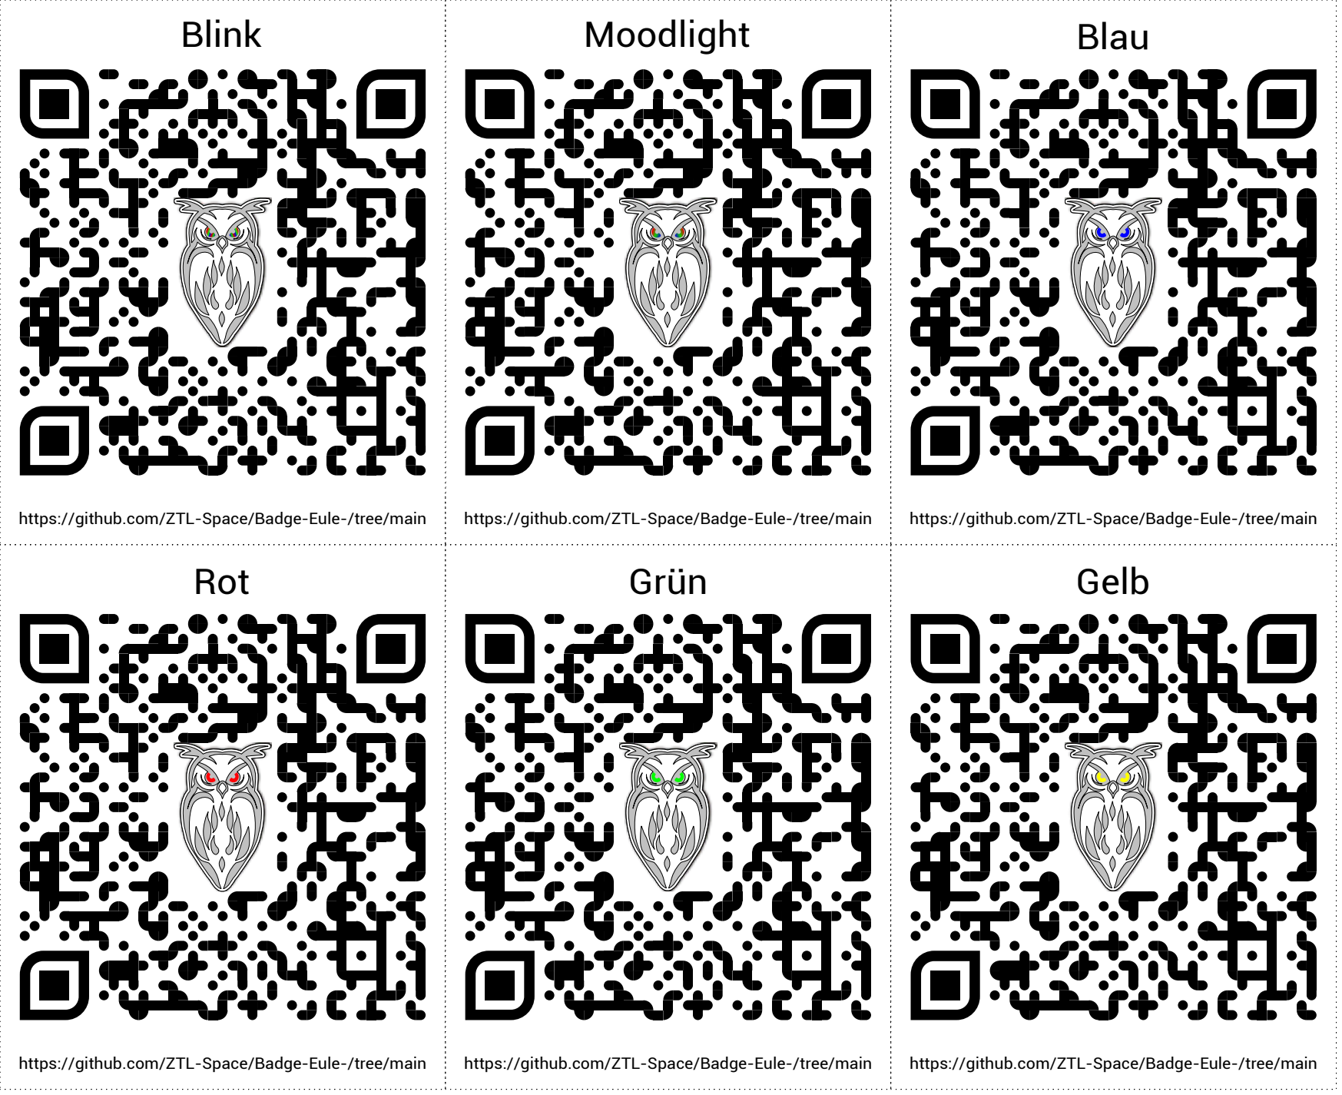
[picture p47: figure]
https://github.com/ZTL-Space/Badge-Eule-/tree/main; Moodlight; Rot; Grün; Gelb; Blau; Blink

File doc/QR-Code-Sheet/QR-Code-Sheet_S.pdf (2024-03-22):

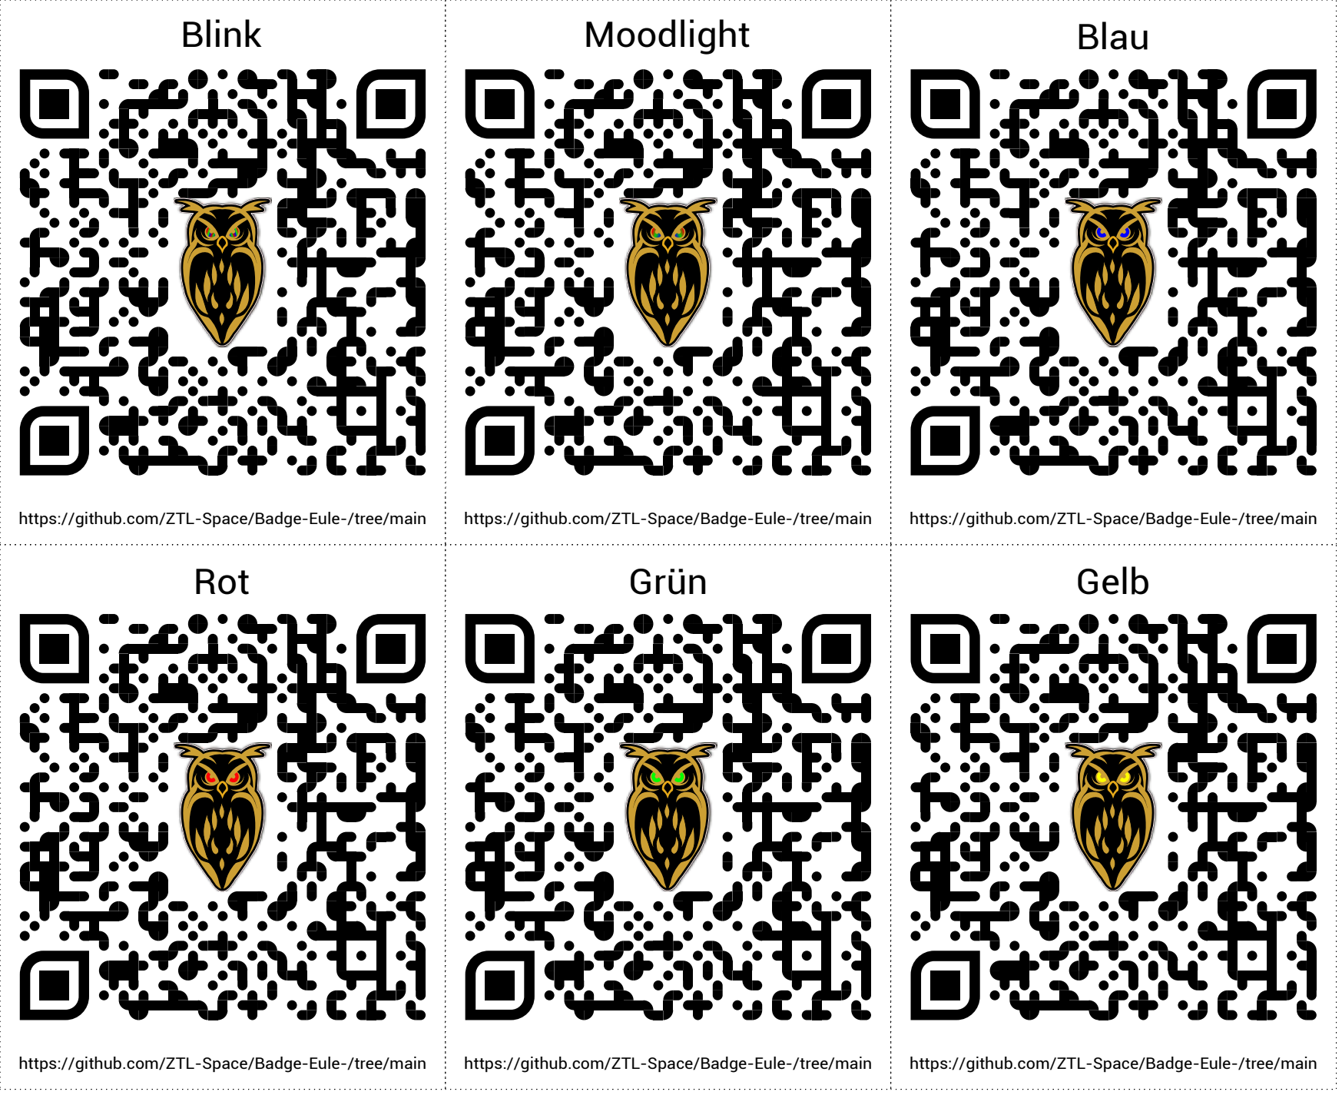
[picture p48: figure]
https://github.com/ZTL-Space/Badge-Eule-/tree/main; Moodlight; Rot; Grün; Gelb; Blau; Blink

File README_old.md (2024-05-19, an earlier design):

# Anleitung

**Entnervte Eule / Obnoxious Owl**

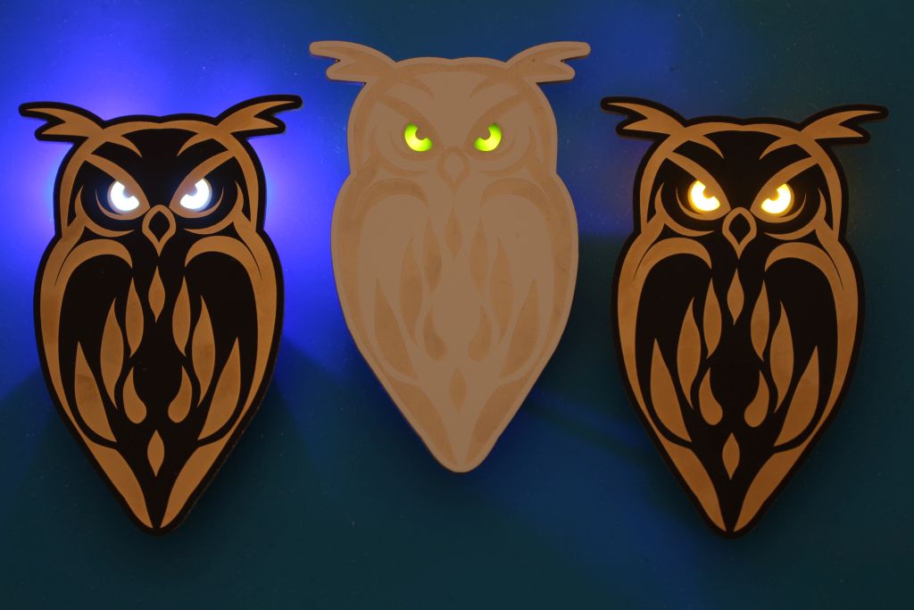
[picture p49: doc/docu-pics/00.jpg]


## Bauteile 

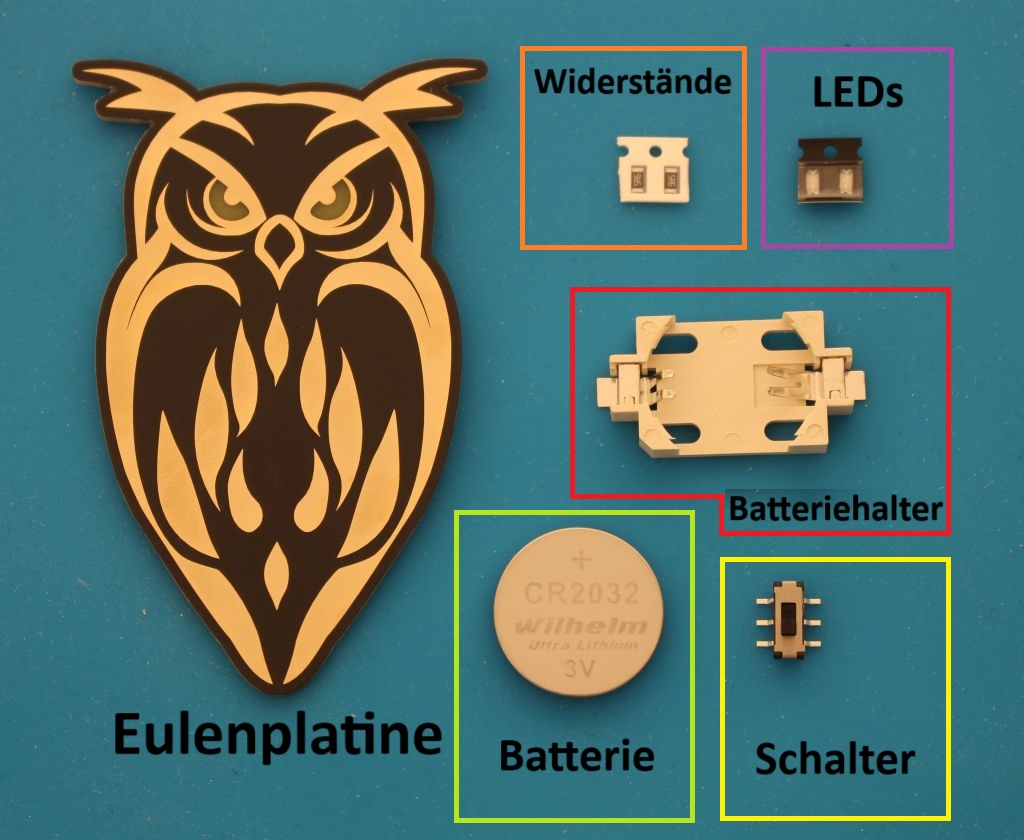
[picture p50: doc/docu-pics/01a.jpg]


- 1x Eulenplatine in Silber/Weiß oder Gold/Schwarz
- 1x Batteriehalter
- 1x Batterie (CR2032 Knopfzelle, 3 Volt)
- 1x Schalter (An-Aus)
- 2x LEDs (verschiedenen Farben möglich)
- 2x Widerstände mit den passenden Werten zu den LEDs

## Benötigte Werkzeuge
- Lötkolben
- Lötzinn
- Pinzette

## Wo kommt was hin?

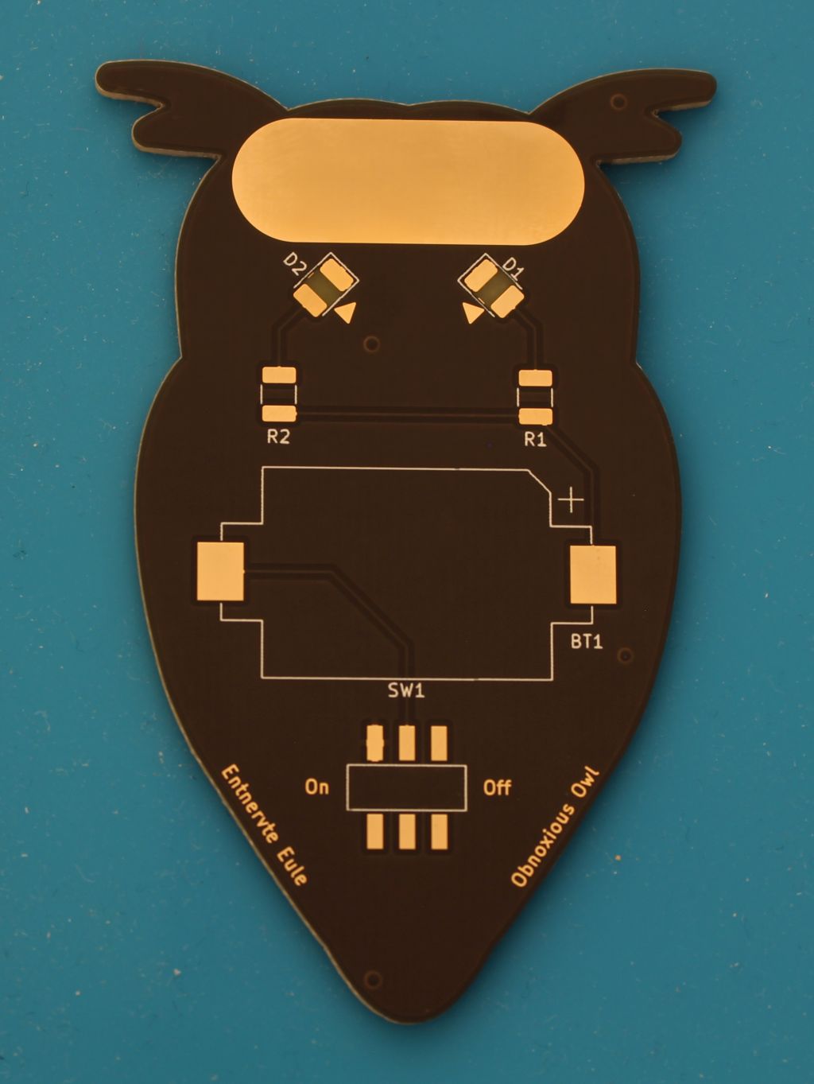
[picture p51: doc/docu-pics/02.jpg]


| Beschriftung | Bauteil |
| :--- | :--- |
| D1/D2 | LEDs |
| R1/R2 | Widerstände |
| BT1 | Batteriehalter |
| SW1 | Schalter |

## Auswahl der LEDs und passende Widerstände

LEDs brauchen je nach Farbe unterschiedliche Spannungswerte. Da unsere Batterie immer 3 Volt ausgibt, müssen wir die Spannung mithilfe von Widerständen anpassen.

Passend zu den LED-Farben im Set sind die richtigen Widerstände schon dabei. 

| LED Farbe | Widerstand  |
| :--- | :--- |
| Rot | 82 Ω |
| Grün | 56 Ω |
| Gelb | 47 Ω |
| Blau | 5,6 Ω |
| Bunt | 0 Ω |

Wenn deine Eule Augen mit unterschiedlichen Farben haben soll, kein Problem: Komm zu uns. Wir suchen dir die richtige Farbkombination heraus.

## Schritt 1
### Widerstände löten (R1, R2)

Zuerst musst du eine Lötstelle vorverzinnen.
Halte hierfür deinen Lötkolben auf die obere Lötstelle und führe dann langsam Lötzinn hinzu.

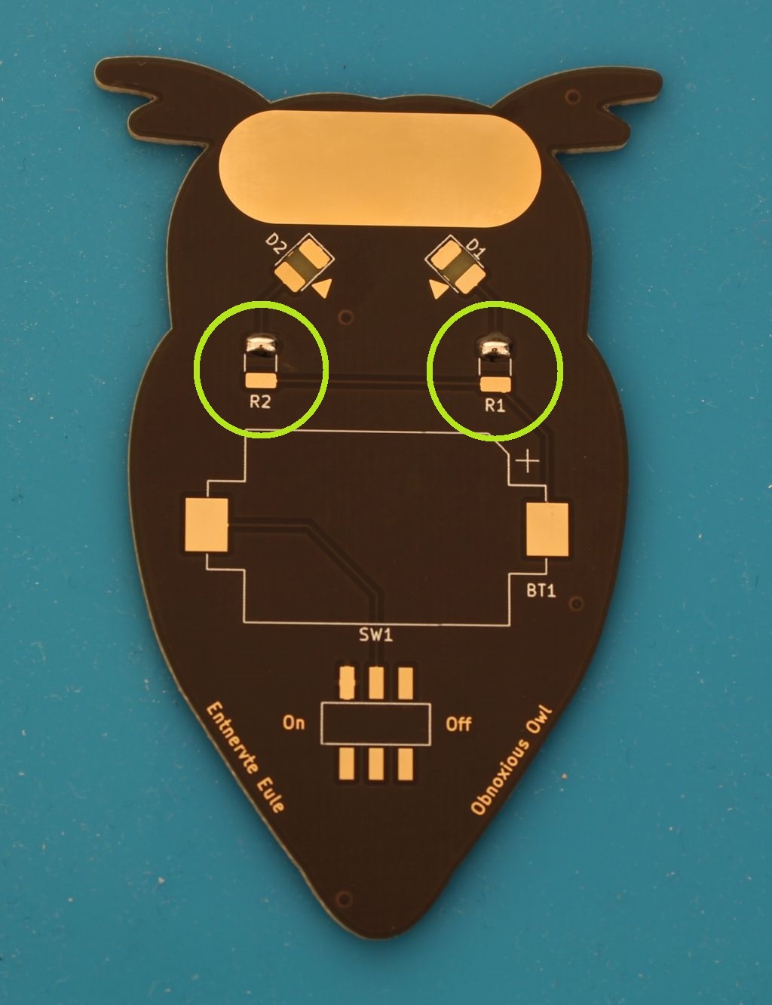
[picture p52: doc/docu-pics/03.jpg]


Bei den Widerständen musst du nicht drauf achten, wie herum sie gedreht sind. Nimm den Widerstand mit einer Pinzette auf. Mit dem Lötkolben in der anderen Hand erhitzt du nochmal das Lötzinn auf der vorverzinnten Stelle.
Wenn das Zinn flüssig ist, schiebst du den Widerstand in Position. 

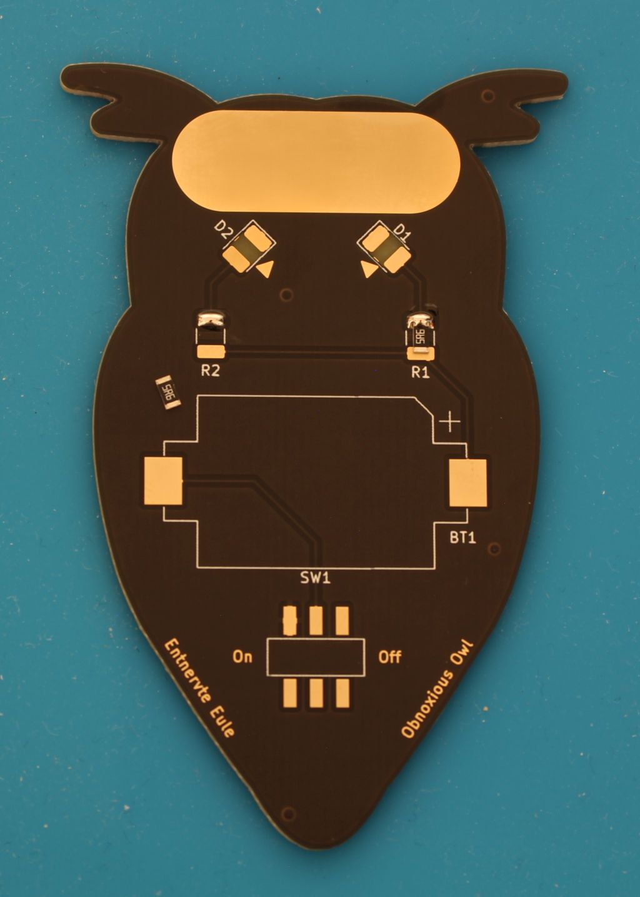
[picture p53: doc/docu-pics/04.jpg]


Anschließend lötest du noch die andere Seite des Widerstands fest.

Beim zweiten Widerstand machst du es genauso nochmal.

## Schritt 2

### LEDs löten (D1, D2)

Zuerst solltest du wieder eine Lötstelle vorverzinnen.

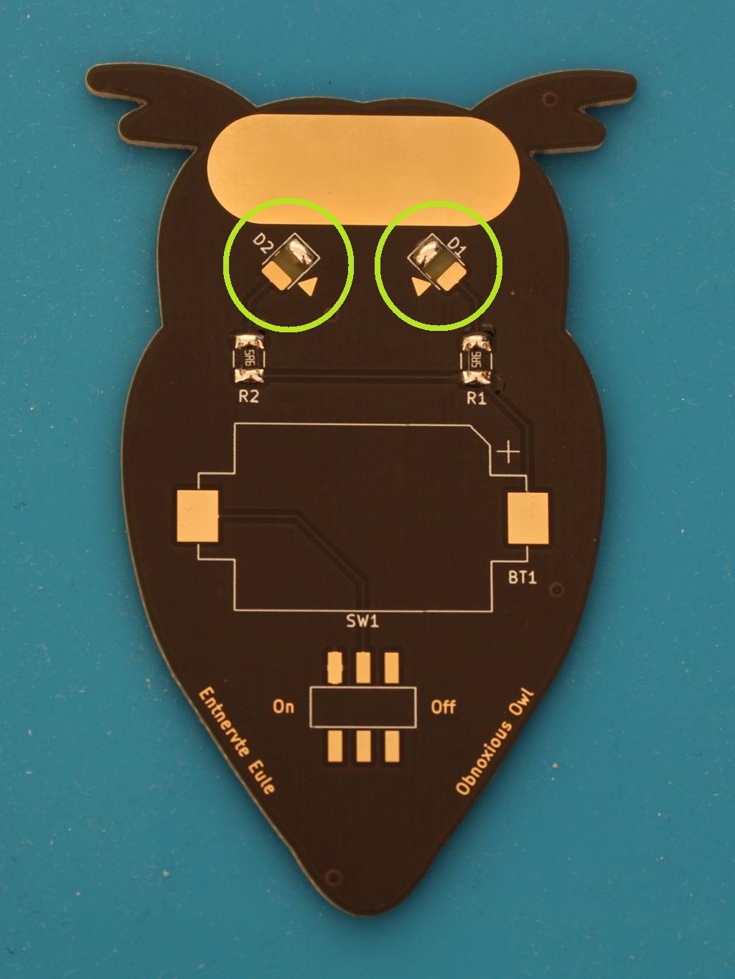
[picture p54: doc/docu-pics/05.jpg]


**Wichtig! Die LEDs haben eine Polung (Richtung). Deshalb musst du darauf achten, sie richtig herum einzulöten. Der Pfeil auf der LED (bzw. das T bei einigen LEDs) muss in die selbe Richtung zeigen wie der Pfeil auf der Platine!**

Du musst die LEDs außerdem mit dem Glaskörper nach unten festlöten. Später soll das Licht auf der anderen Seite der Platine zu sehen sein. 

Wie schon bei den Widerständen nimmst du die LED mit der Pinzette. Mit dem Lötkolben erhitzt du nochmal die verzinnte Lötstelle. Achte auf die Richtung der LED!
Wenn die LED fest ist, lötest du wieder den anderen Pin fest.

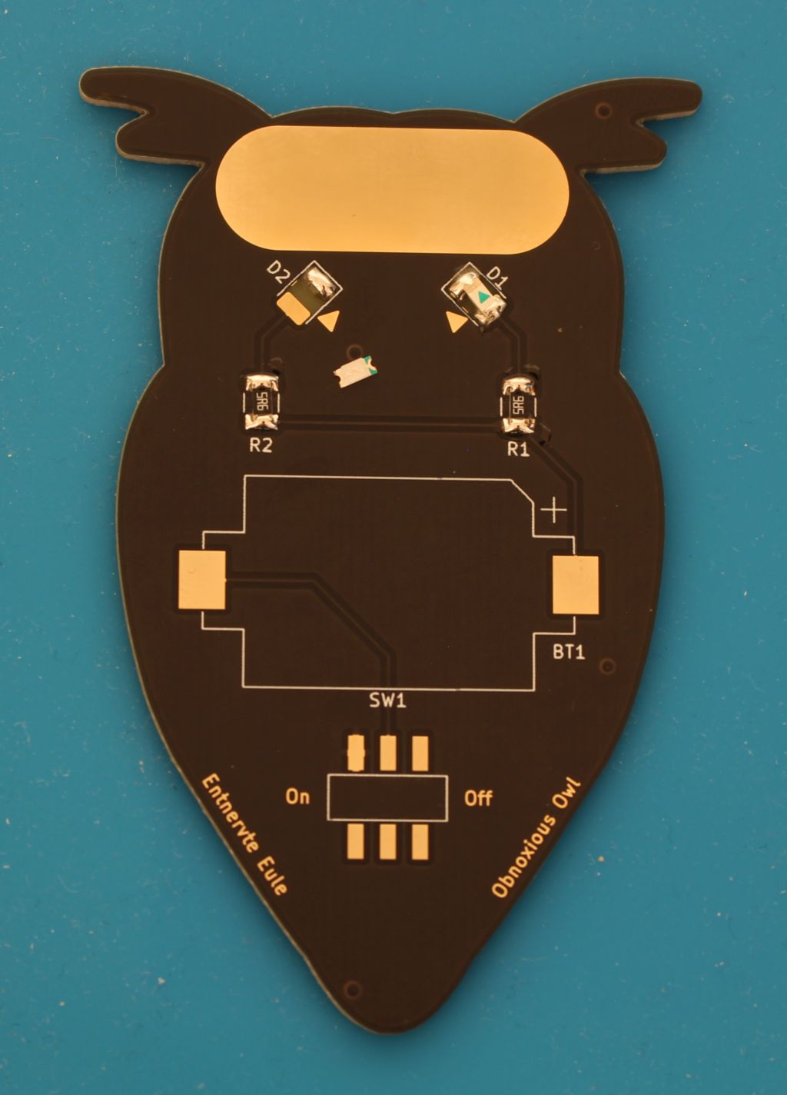
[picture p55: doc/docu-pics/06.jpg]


Das Ganze wiederholst du mit der zweiten LED.

## Schritt 3

### Schalter löten

Den Schalter lötest du genau wie die anderen Teile. Zuerst musst du wieder vorverzinnen. Wie immer erstmal nur eine Lötstelle.

Du nimmst den Schalter dann mit der Pinzette, erhitzt das Zinn und schiebst das Beinchen in das flüssige Zinn. Achte darauf, dass die anderen Beinchen des Schalters richtig auf den Pads (Lötstellen) liegen.

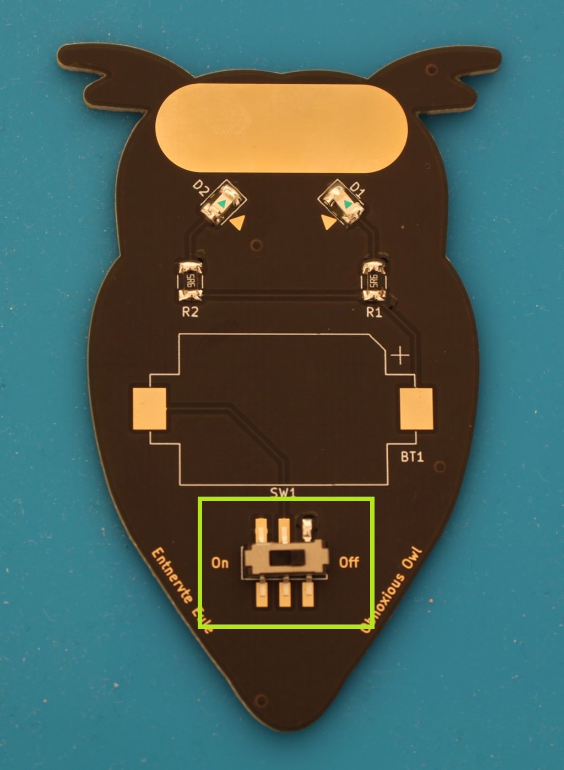
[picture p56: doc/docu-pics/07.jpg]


Wenn du den Schalter wie beschrieben befestigt hast, lötest du noch die restlichen Beinchen fest.

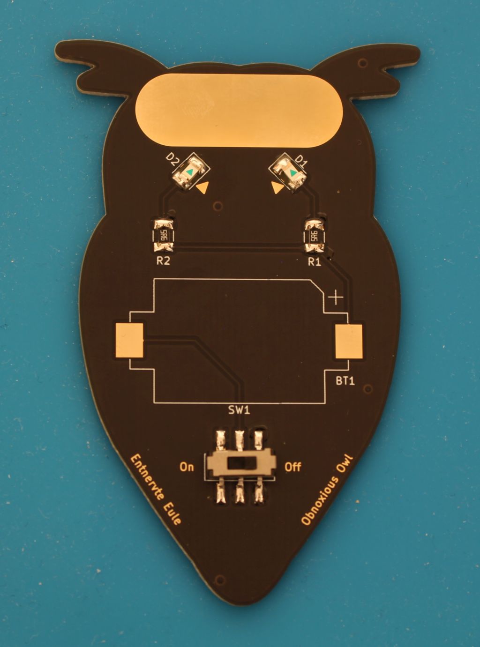
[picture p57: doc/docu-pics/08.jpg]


## Schritt 4
### Batteriehalter löten

Auch hier musst du die Lötstelle wieder vorverzinnen.

**Wichtig! Achte auf die Orientierung des Batteriehalters. Die Abkantung des Batteriehalters muss mit dem Aufdruck übereinstimmen. Wie schon die LED hat auch eine Batterie eine Polung (Plus und Minus).**

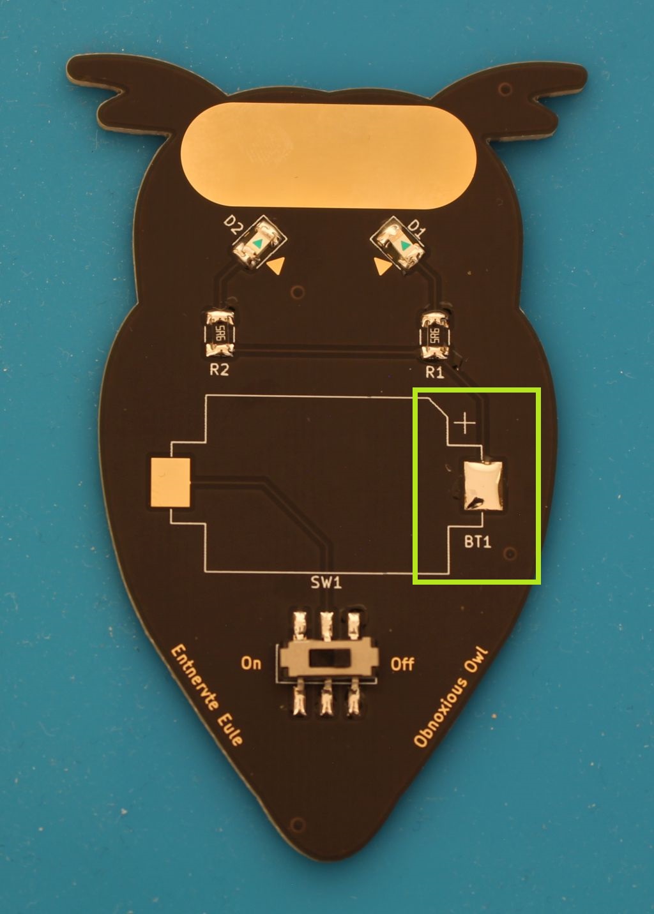
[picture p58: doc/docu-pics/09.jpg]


Jetzt erhitzt du mit dem Lötkolben die verzinnte Lötstelle und
schiebst den Batteriehalter darauf. Da die Lötstelle sehr groß ist, ist es hilfreich, die Spitze des Lötkolbens eher flach aufzusetzen. 

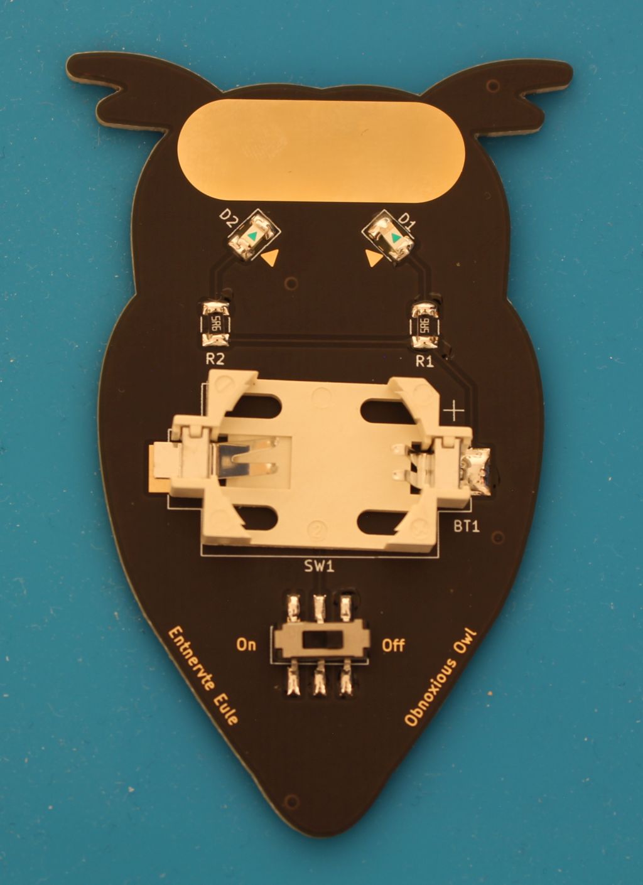
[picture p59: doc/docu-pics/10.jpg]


Jetzt noch die andere Seite festlöten und du hast es geschafft!

## Schritt 5
### Batterie einsetzen und Testen

Jetzt bist du fertig mit dem Löten. Allerdings brauchst du noch eine Spannungsquelle, bevor die Eule funktioniert. Bei der Batterie musst du darauf achten, sie richtig herum einzusetzen. Die Seite mit dem "+" und der Schrift muss nach oben zu dir zeigen.

Die Batterie muss schräg in den Batteriehalter eingelget werden, sodass die Plus-Kontakte (rechts) mit der Oberseite der Batterie verbunden sind.

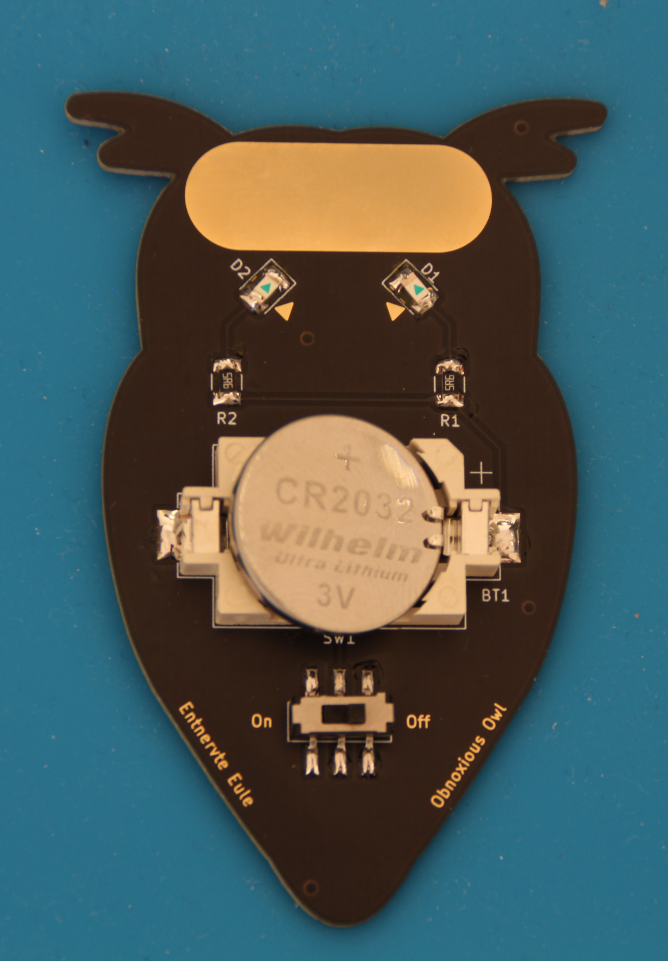
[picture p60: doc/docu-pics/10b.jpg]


Ist die Batterie korrekt platziert, musst du sie mit einiger Kraft (am besten mit dem Daumen) in den Halter drücken.

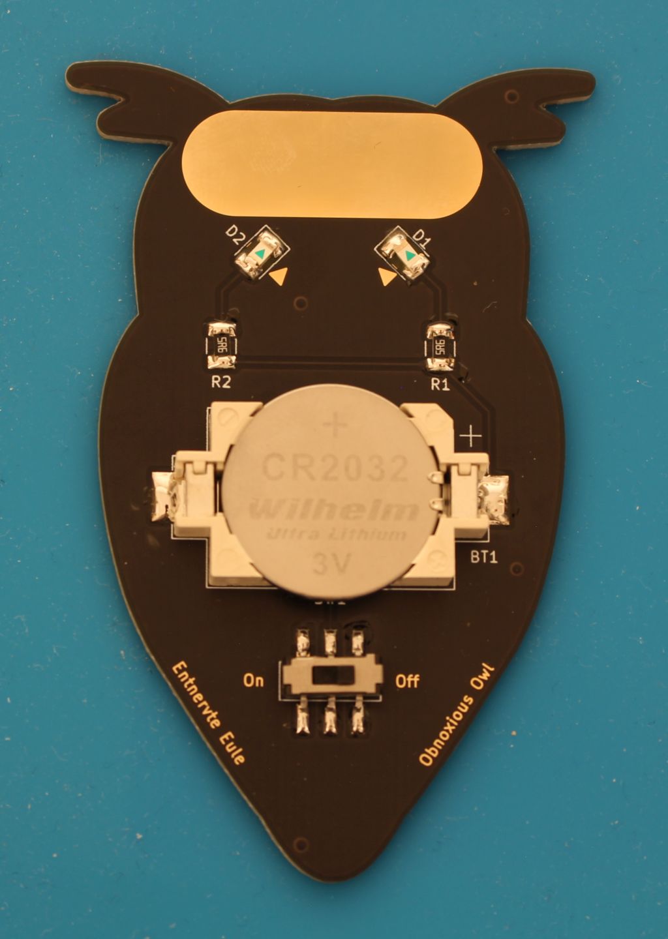
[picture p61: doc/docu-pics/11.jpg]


Ist die Batterie eingebaut, kannst du die Eule mit dem Schalter einschalten. Im besten Fall fangen jetzt ihre Augen an zu leuchten. Toll gemacht! 

Wenn deine Eule nicht anfängt zu leuchten, kein Problem: Komm zu uns. Wir schauen zusammen nach dem Fehler und helfen dir, es zu beheben.

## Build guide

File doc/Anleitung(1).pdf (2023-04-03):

# Anleitung

Entnervte Eule
Obnoxious Owl

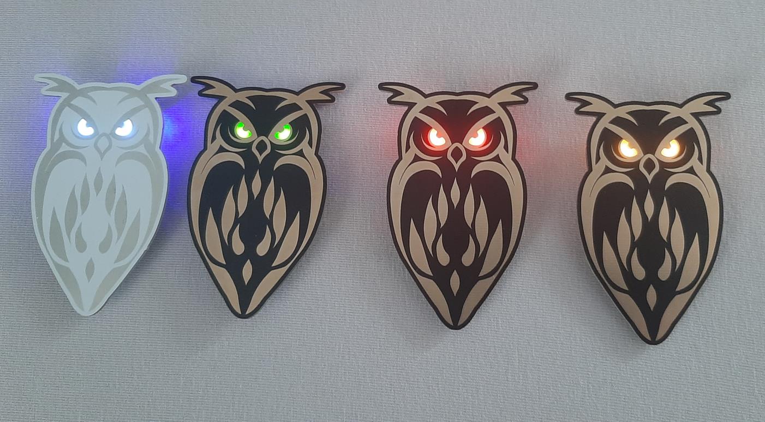
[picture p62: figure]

## Platine

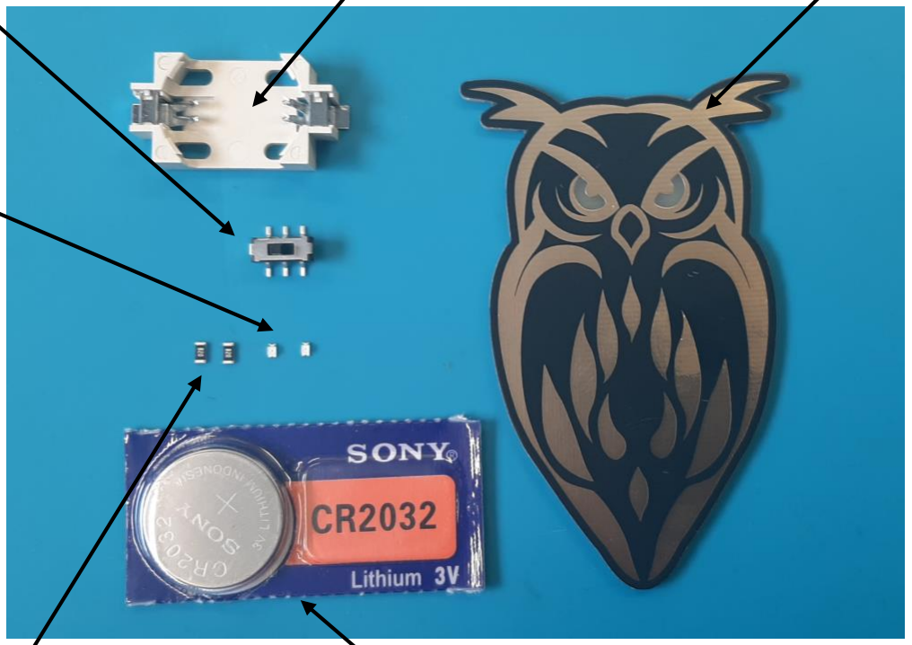
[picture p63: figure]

## Widerstände

## Schalter

## LEDs

## Batteriehalter

## Batterie

# Bauteile

1x Platine in Silber oder Gold 1x Batteriehalter
1x Batterie 3 Volt
1x Schalter (An-Aus)
2x LEDs in verschiedenen Farben
2x Widerstände mit verschiedenen Werten

# Wo kommt was hin ?

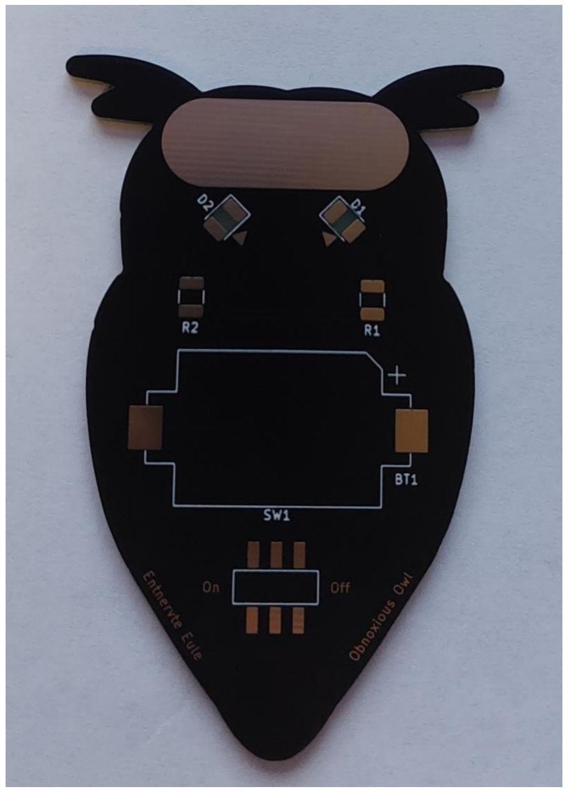
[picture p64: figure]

D1/D2 | LEDs
R1/R2 | Widerstände
BT1 | Batteriehalter
SW1 | Schalter

# Auswahl der LEDs

und die dazugehörigen Widerstände

Rot | 82 Ω
Grün | 56 Ω
Blau | 5,6 Ω
Gelb | 47 Ω

Verschiedene LEDs brauchen unterschiedliche Spannungen. Da unsere Batterie 3 Volt ausgibt, müssen wir die Spannung mithilfe von Widerständen herabsetzen.

Suche dir alle Bauteile zusammen, die du benötigst. Wähle die Farben deiner LEDs und hole dir die entsprechenden Widerstände.

# Schritt 1

Widerstände einlöten (R1, R2)

Zuerst müssen wir die
Lötstelle vorverzinnen.
Halte hierfür deinen
Lötkolben auf die obere
Lötstelle und führe dann
langsam Lötzinn hinzu.

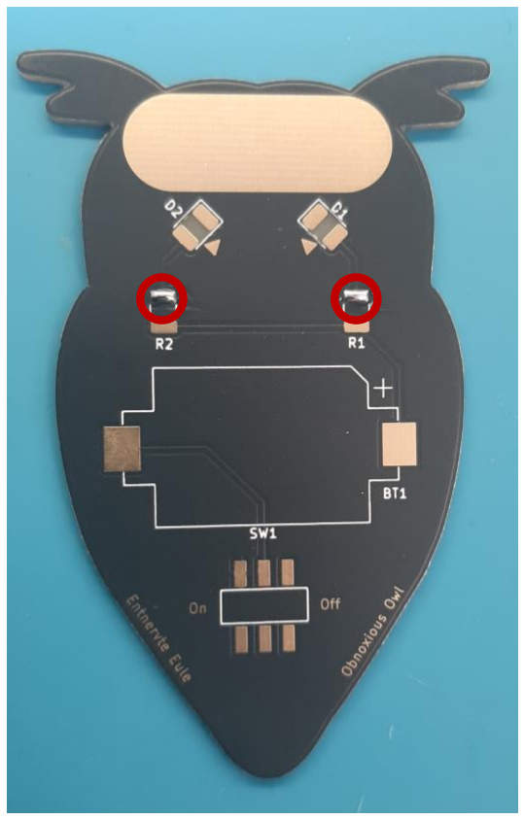
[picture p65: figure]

Jetzt nimmst du den
Widerstand mit der
Pinzette in der einen Hand und mit der andere Hand
erhitzt du das Lötzinn.
Wenn das Zinn flüssig ist, schiebst du den
Widerstand in Position.
Anschließend löten wir
noch die untere Seite an.

Diesen Schritt wiederholst du auf der anderen Seite.

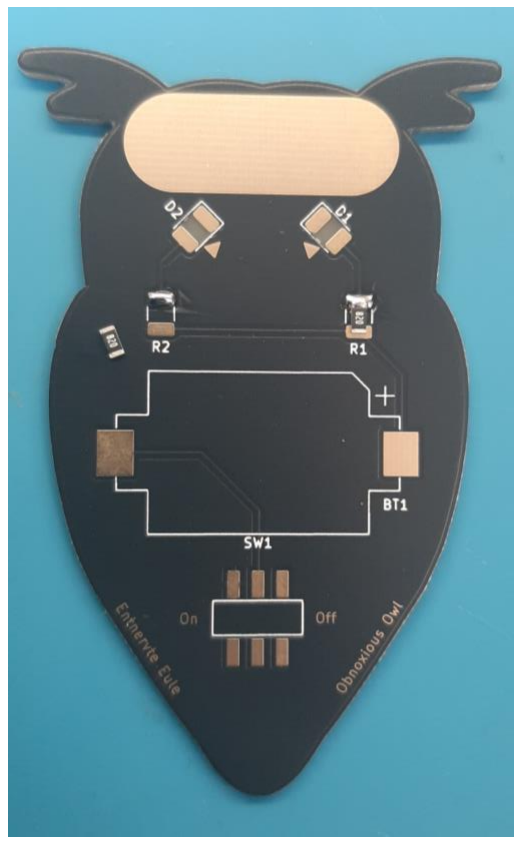
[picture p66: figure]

Bei den Widerständen musst du nicht drauf achten wie rum sie sind.

# Schritt 2

LEDs löten (D1, D2)

Zuerst müssen wir die Stelle wieder vorverzinnen. Dieses Mal musst du mehr Lötzinn
aufbringen.

Wichtig!

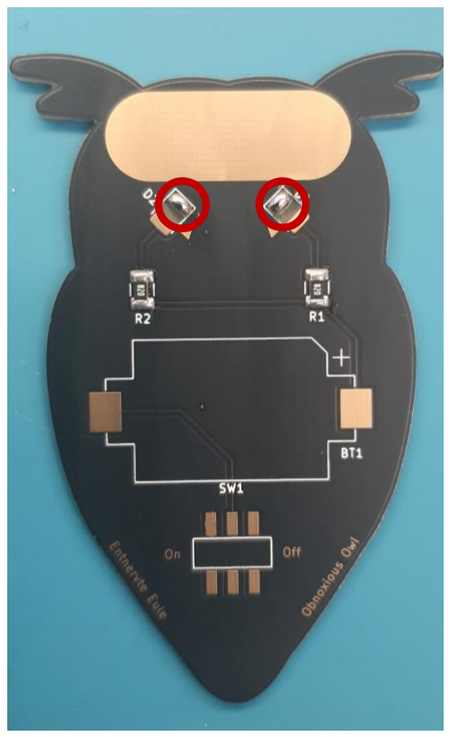
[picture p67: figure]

Die LEDs haben eine Polung und müssen richtig herum eingebaut werden. Der Pfeil auf der LED muss in die selbe Richtung zeigen wie der Pfeil daneben.

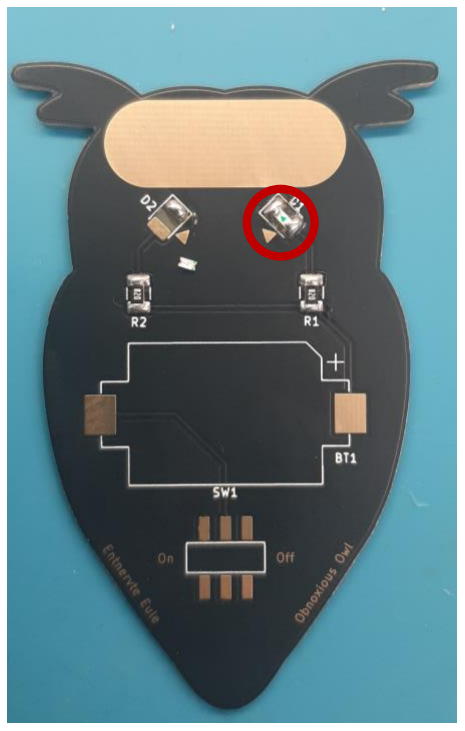
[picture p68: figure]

Wir müssen die LEDs falschherum festlöten, da wir wollen, dass sie nach unten leuchten. Wie bei den Widerständen nimmst du die LED mit der Pinzette und mit dem Lötkolben erhitzt du die Lötstelle. Achte auf die Richtung der LEDs. Wenn die LED fest ist, löten wir noch den anderen Pin fest.

Dies wiederholst du auf der andere Seite mit der zweiten LED.

# Schritt 3

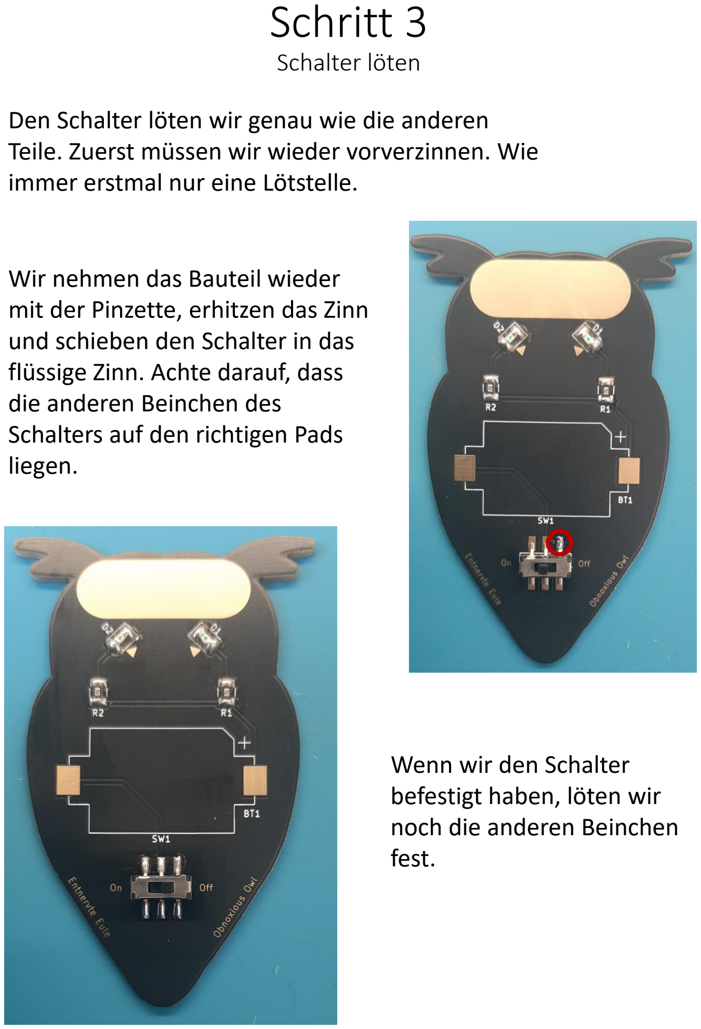
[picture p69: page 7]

Schalter löten

Den Schalter löten wir genau wie die anderen Teile. Zuerst müssen wir wieder vorverzinnen. Wie immer erstmal nur eine Lötstelle.

Wir nehmen das Bauteil wieder
mit der Pinzette, erhitzen das Zinn und schieben den Schalter in das flüssige Zinn. Achte darauf, dass die anderen Beinchen des
Schalters auf den richtigen Pads liegen.

Wenn wir den Schalter
befestigt haben, löten wir noch die anderen Beinchen
fest.

# Schritt 4

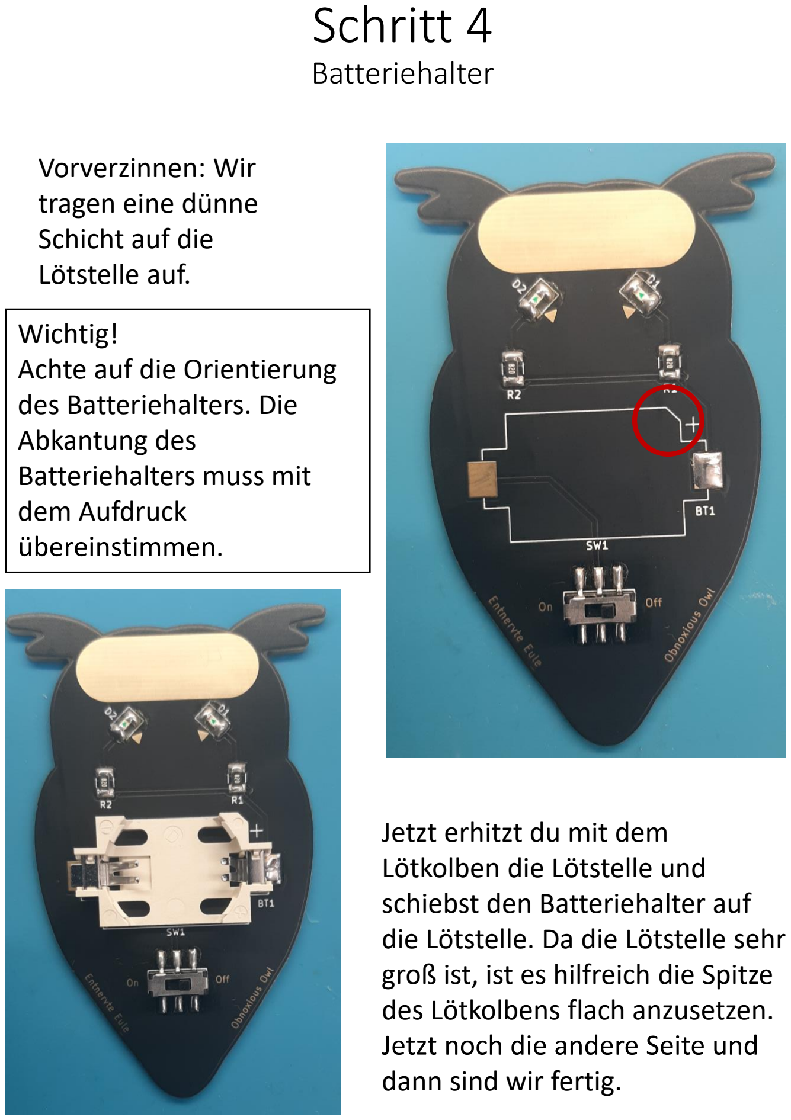
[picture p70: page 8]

Batteriehalter

Vorverzinnen: Wir
tragen eine dünne
Schicht auf die
Lötstelle auf.

Wichtig!
Achte auf die Orientierung des Batteriehalters. Die
Abkantung des
Batteriehalters muss mit
dem Aufdruck
übereinstimmen.

Jetzt erhitzt du mit dem
Lötkolben die Lötstelle und schiebst den Batteriehalter auf die Lötstelle. Da die Lötstelle sehr groß ist, ist es hilfreich die Spitze des Lötkolbens flach anzusetzen. Jetzt noch die andere Seite und dann sind wir fertig.

# Schritt 5

Batterie und Testen

Jetzt sind wir fertig mit dem Löten. Allerdings benötigen wir noch eine Stromquelle. Bei der Batterie müssen wir darauf achten, dass sie richtig herum eingesetzt wird. Die Seite mit dem Plus muss nach oben zeigen.

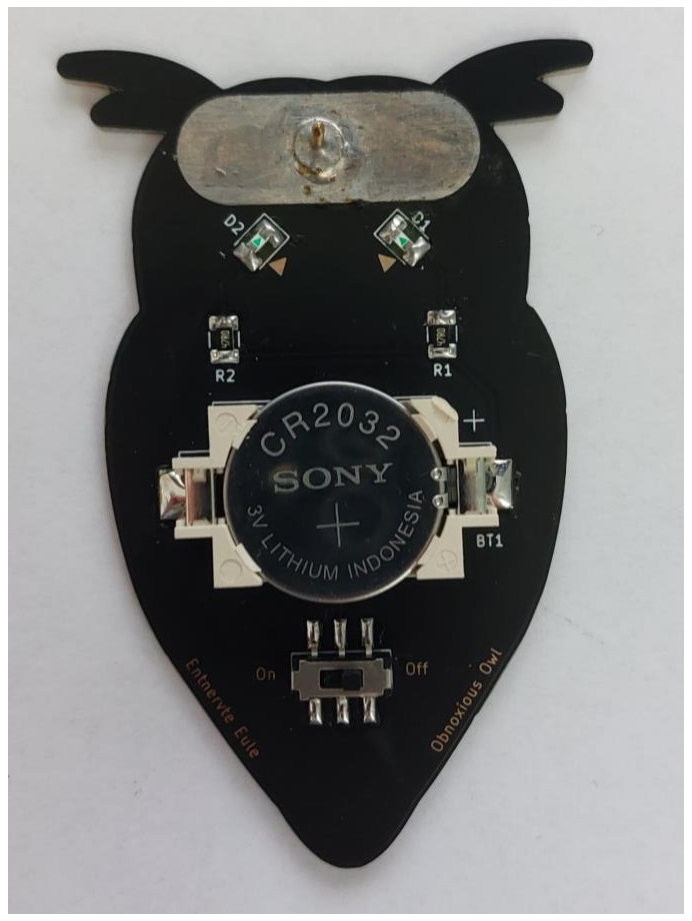
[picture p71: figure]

Wenn die Batterie eingebaut ist, kannst du sie zum ersten Mal anschalten.
Im besten Fall fängt sie an zu leuchten.
Wenn deine Eule nicht anfängt zu leuchten, komm zu uns und wir schauen, ob wir den Fehler gemeinsam finden können.

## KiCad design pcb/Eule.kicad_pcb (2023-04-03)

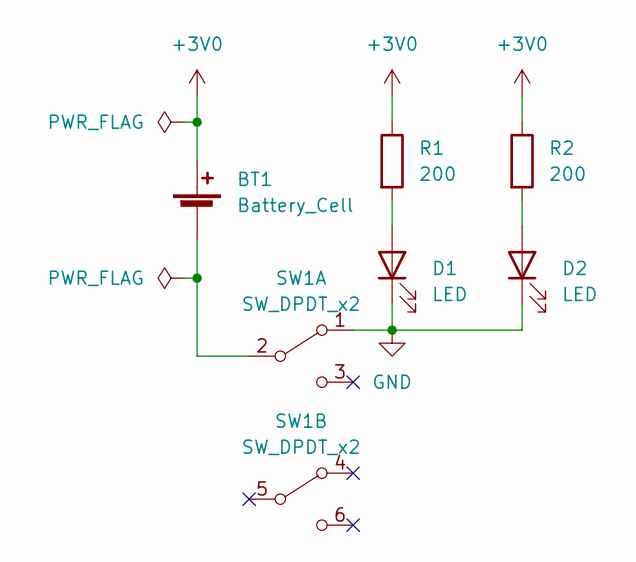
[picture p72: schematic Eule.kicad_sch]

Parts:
BT1: Battery_Cell; BatteryHolder_Keystone_1060_1x2032
D1, D2: LED; LED_1210_3225Metric_Pad1.42x2.65mm_HandSolder
R1, R2: 200; R_1210_3225Metric_Pad1.30x2.65mm_HandSolder
SW1: SW_DPDT_x2; MSS22D18G2

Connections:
+3V0: BT1.1 (+), R1.1, R2.1
GND: D1.1 (K), D2.1 (K), SW1.1 (A)
unnamed: BT1.2 (-), SW1.2 (B)
unnamed: D1.2 (A), R1.2
unnamed: D2.2 (A), R2.2

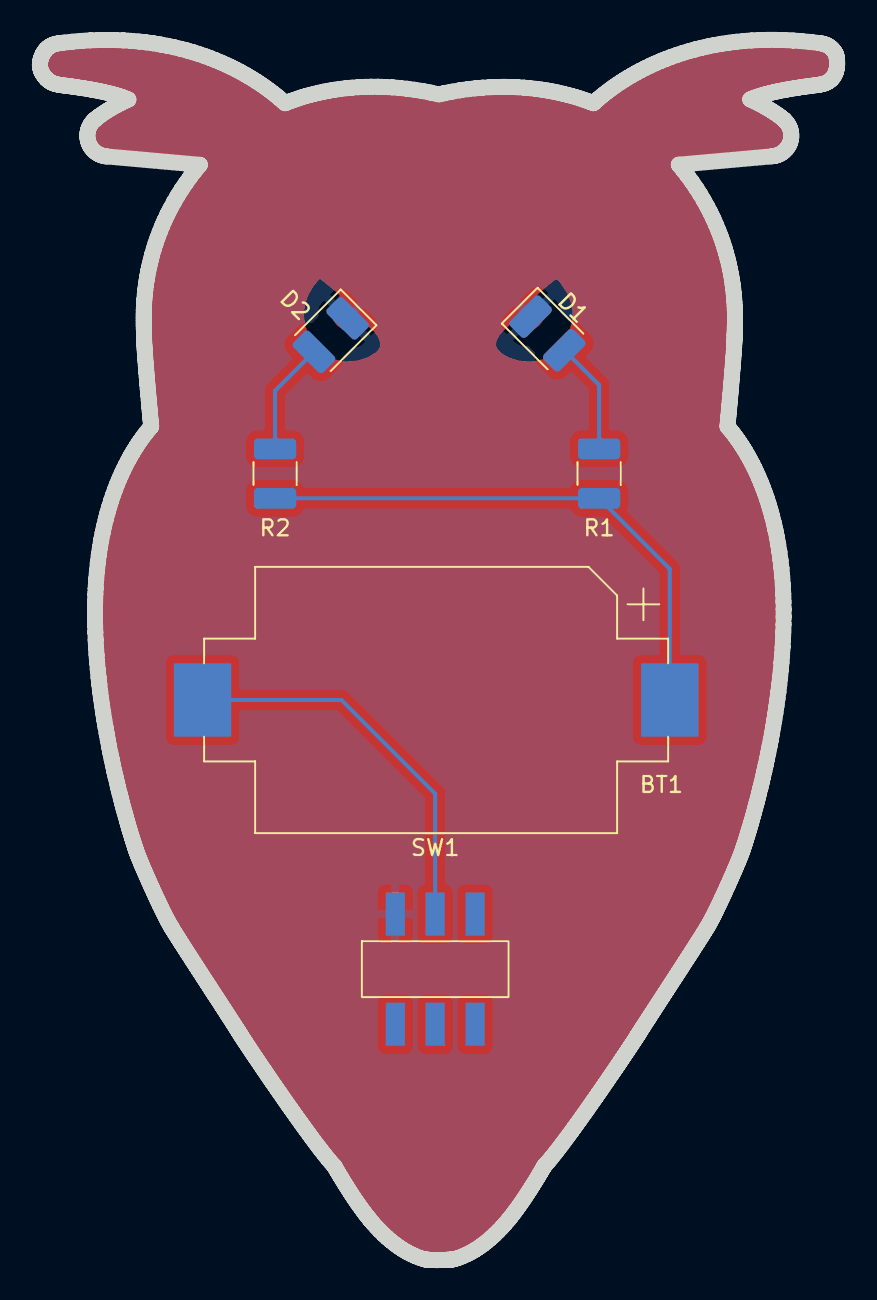
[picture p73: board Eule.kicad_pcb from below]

Board: 2 copper layers, 50.0 x 76.5 mm, 6 parts (6 on the bottom side), 5 nets.

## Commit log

2023-01-13 generated gerber v1.0
    [Eule-B_Cu.gbl, Eule-B_Mask.gbs, Eule-B_Paste.gbp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]
2023-01-13 fixed eyes
    [Eule-B_Cu.gbl, Eule-B_Mask.gbs, Eule-B_Paste.gbp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]
2023-02-02 v2.0
    changed switch
    increased footprint for batterie holder
    text
    [Eule-B_Cu.gbl, Eule-B_Mask.gbs, Eule-B_Paste.gbp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]
2023-02-02 update bom
2023-02-21 footprint enlarged Text changes LED arrow
    [Eule-B_Cu.gbl, Eule-B_Mask.gbs, Eule-B_Paste.gbp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]
2024-03-25 add tray insert
2024-03-28 Bilder für die Doku
    Bilder für die Doku hinzugefügt
2024-05-19 Update Doku - Einlegen der Batterie
2025-06-11 optimize readme for print
2025-06-11 add readme as html to print
